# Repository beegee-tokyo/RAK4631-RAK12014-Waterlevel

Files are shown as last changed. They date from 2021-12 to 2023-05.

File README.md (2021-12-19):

----
----
# _RAK12014 Laser TOF sensor coming soon_
----
----

# WisBlock Watertank Level Sensor

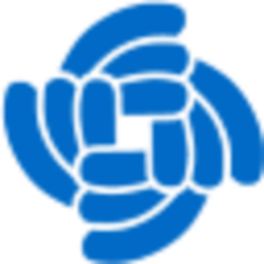
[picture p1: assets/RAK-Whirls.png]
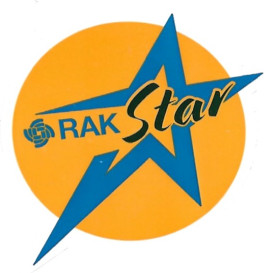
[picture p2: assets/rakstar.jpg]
RAKstar
|  |  | RAKstar | 
| :-: | :-: | :-: |

Watertank Overflow detection using the **RAKwireless WisBlock** modules. It implements as well a trick to wake up the device from sleep by knocking on the enclosure. 

## _REMARK_
The code is based on my low power event driven [WisBlock API](https://github.com/beegee-tokyo/WisBlock-API)

----

# Background
Here in the Philippines it is essential to have a water tank, because it is (unfortunately) still quite common that the water supply is cut off.    
After I got my tank installed, I experienced several time that the floating valve that controls the refill of the tank got stuck and the tank was overflowing for hours before I detected it.    
As there is no outlet close to the water tank, I needed a low power, solar recharged overflow sensor that can transmit the data over a longer distance.     
**RAKWireless WisBlock** has all components I needed to build my overflow sensor.    
- **RAK19003 & RAK4631** ==> The base board, battery supply, solar charger, MCU with LPWAN capability
- **RAK12014** ==> WisBlock Laser ToF sensor to measure the water level
- **RAK1904** ==> Acceleration sensor. This is not used for the overflow detection, it is used to wake up the system and activate the BLE. As the system is sleeping most of the time the BLE is of course switched off to save battery. I needed a solution to wake up the MCU and activate the BLE, so that I can access the device and setup its parameters. To wake up the system, you knock-knock on the enclosure. This vibrations are detected by the acceleration sensor, which generates an interrupt to wake up the system.
- **Solar Board** => A small 5V solar panel to recharge the battery during the day.

The enclosure is not IP65 but can protect the electronics from water intrusion unless the device is submerged into the water. It was designed using Fusion 360. The data files for the enclosure and the small solar panel can be found in the [./assets/3D](./assets/3D) folder.

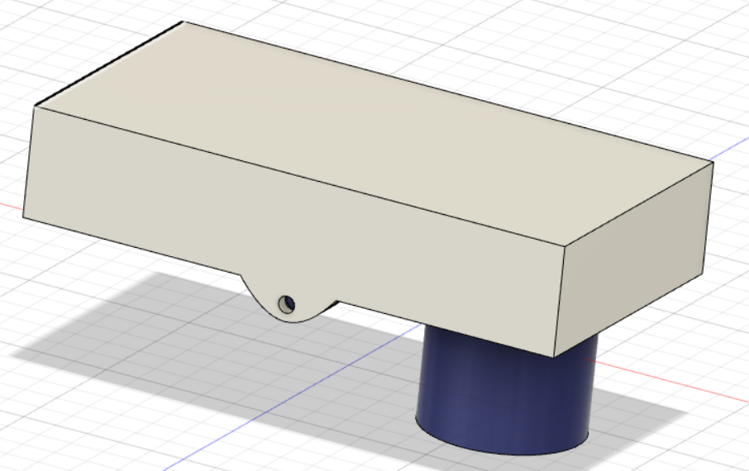
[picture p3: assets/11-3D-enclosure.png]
Enclosure
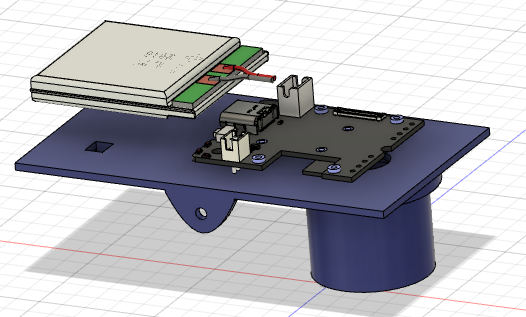
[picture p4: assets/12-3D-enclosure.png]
Enclosure
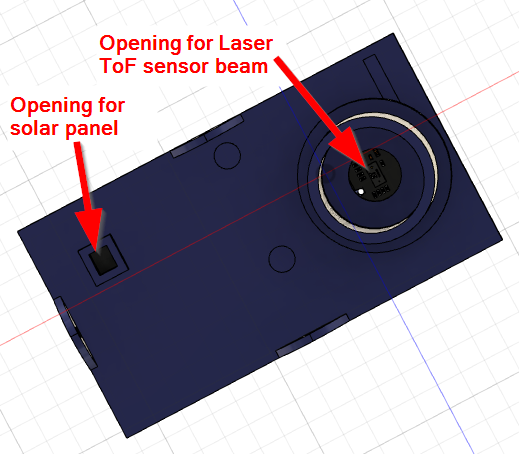
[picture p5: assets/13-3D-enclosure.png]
Enclosure
|  |  |  | 
| :-: | :-: | :-: |

# Dataflow
The sensor wakes up every 1 minute (configurable) and measures the distance between the Laser ToF sensor and the water surface. It packs the data into a data package in [Cayenne LPP format](https://community.mydevices.com/t/cayenne-lpp-2-0/7510) and includes:    
- Alarm status Overflow (digital output)
- Alarm status Low Level (digital output)
- Measured distance to water level (analog output). It is not the calculated water level, just the value read from the Laser ToF sensor. For my water tank the distance between the sensor and the bottom is around 1200mm. If the measured distance is larger than that, the value is discarded. The reason that such values are measured is because the water surface is not an ideal surface for measurement with the Laser ToF. Waves, sprinkling water while refilling can lead to false values.      
At a level of ~20, the water level is just below the sensor and the tank starts to overflow.    
- The battery level of the system (analog output).

The data format is
```c++
uint8_t data_flag0 = 0x01; // 1 Channel # 1
uint8_t data_flag1 = 0x02; // 2 Analog Input
uint8_t level_1 = 0;	   // 3 Water level
uint8_t level_2 = 0;	   // 4 Water level
uint8_t data_flag2 = 0x02; // 5 Channel # 2
uint8_t data_flag3 = 0x02; // 6 Analog Input
uint8_t batt_1 = 0;	   // 7 Battery level
uint8_t batt_2 = 0;	   // 8 Battery level
uint8_t data_flag4 = 0x03; // 9 Channel # 3
uint8_t data_flag5 = 0x66; // 10 Presence sensor (Alarm)
uint8_t alarm_of = 0;	   // 11 Alarm flag overflow
uint8_t data_flag6 = 0x04; // 12 Channel # 4
uint8_t data_flag7 = 0x66; // 13 Presence sensor (Alarm)
uint8_t alarm_ll = 0;	   // 14 Alarm flag low level
```

The data is sent as a LPWAN packet over a [RAK7258 gateway](https://docs.rakwireless.com/Product-Categories/WisGate/RAK7258/Overview) to a local Chirpstack LPWAN server.    
The Chirpstack LPWAN server has two integrations enabled:
- Datacake. Instructions can be found in [Chirpstack to Datacake tutorial](https://news.rakwireless.com/how-to-visualize-your-sensor-data-on-datacake-using-chirpstack-server/)
- Cayenne LPP MyDevices    

Once Chirpstack has received a data packet for the Overflow sensor, it forwards the data to the two integrations.    
I used Datacake because it is a very comfortable tool to visualize the data:      

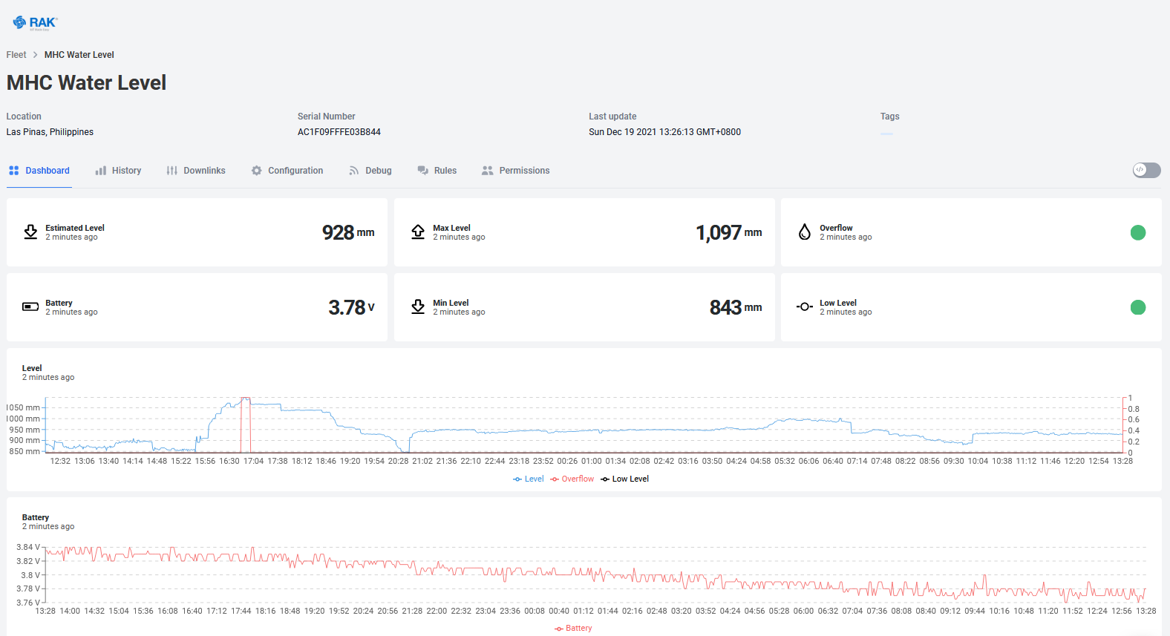
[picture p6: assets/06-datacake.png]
Datacake Dashboard
    

In Datacake you can setup _**rules**_ that can send out on email on events. I use it to send an email if the Alarm value is true:

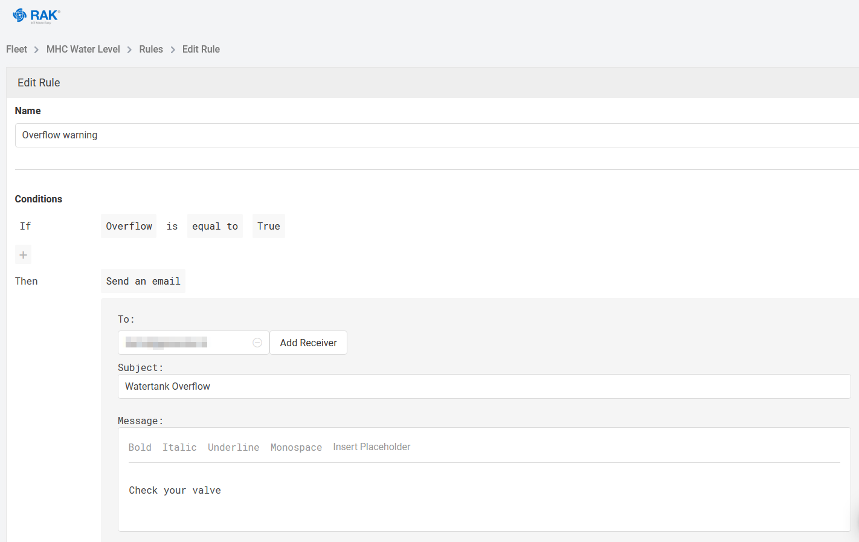
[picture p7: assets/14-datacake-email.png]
Datacake Email


And I added Cayenne LPP MyDevices, because it has more features to take actions on events by using _**triggers**_.

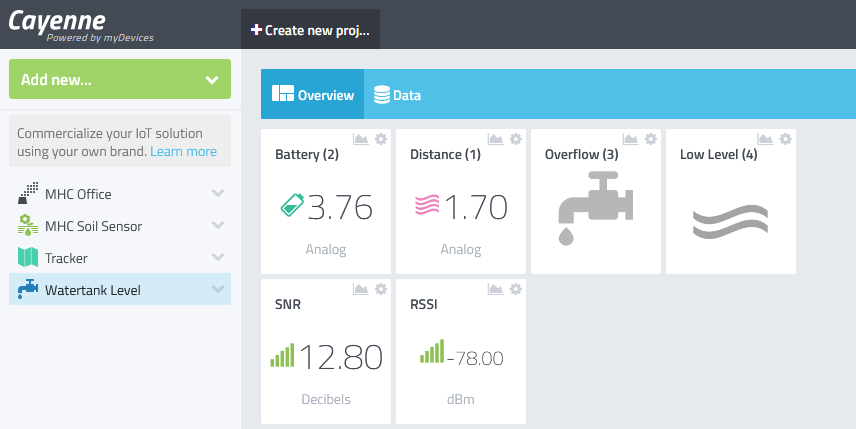
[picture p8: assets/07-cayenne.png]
Cayenne Dashboard
    

The data **`Alarm`** is connected to a Cayenne LPP MyDevices _**trigger**_ that sends an email and a text message if the overflow sensor sends an alarm:    

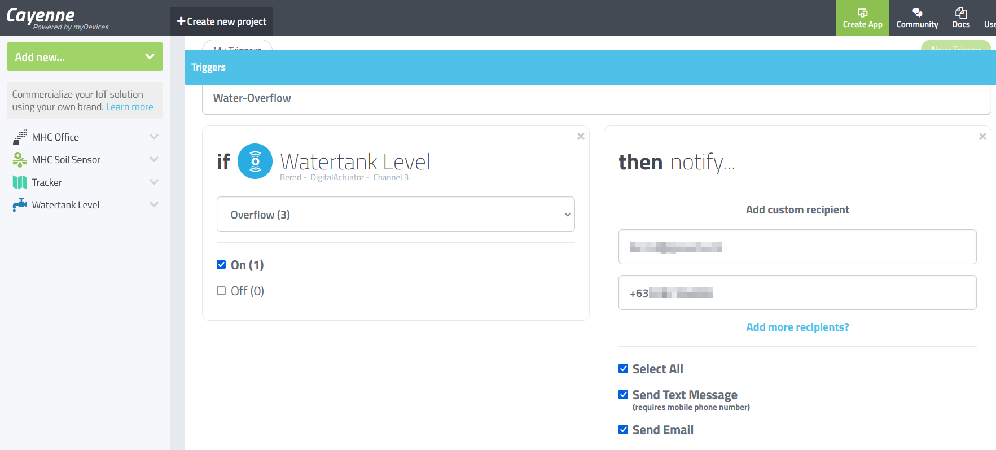
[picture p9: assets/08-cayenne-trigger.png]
Cayenne Alarm Trigger
    

The received alarm messages:

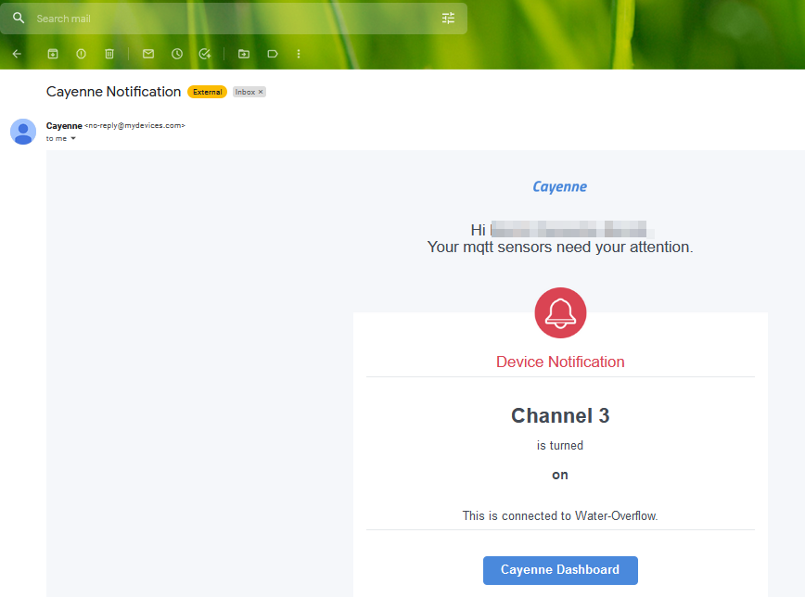
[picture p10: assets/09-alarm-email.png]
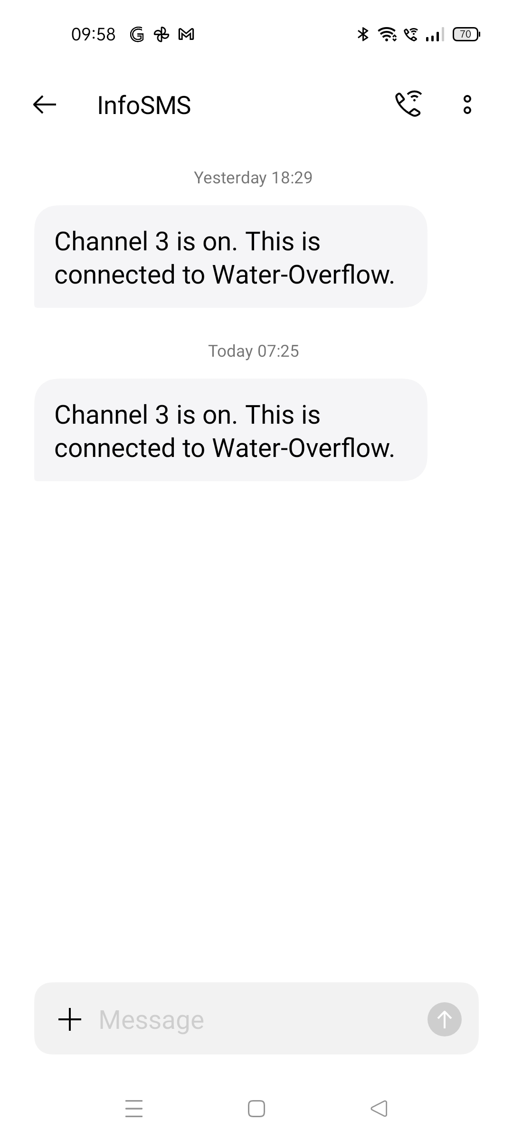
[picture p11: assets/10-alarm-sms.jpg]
|  |  | 
| :-: | :-: |

----

# Power supply and assembly of the sensor
The sensor uses a small 400mAh battery, which is sufficient for this application, as the sensor is only 10 seconds active every 1 minute.     
The battery is recharged during the day by a solar panel. The panel I used is 5V output panel, so that I can directly connect it to the WisBlock Base board.

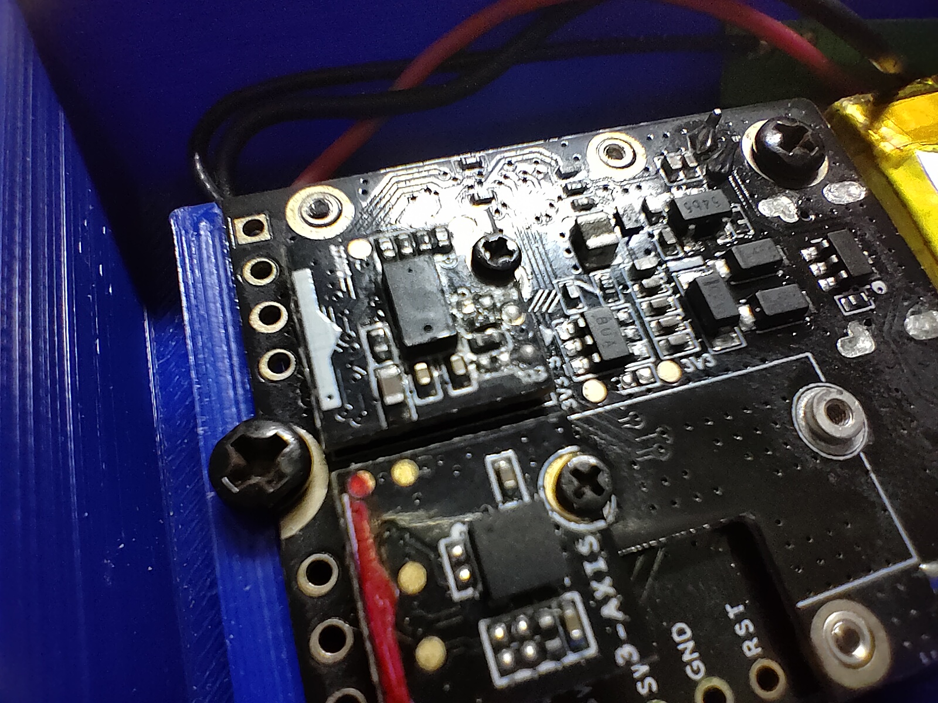
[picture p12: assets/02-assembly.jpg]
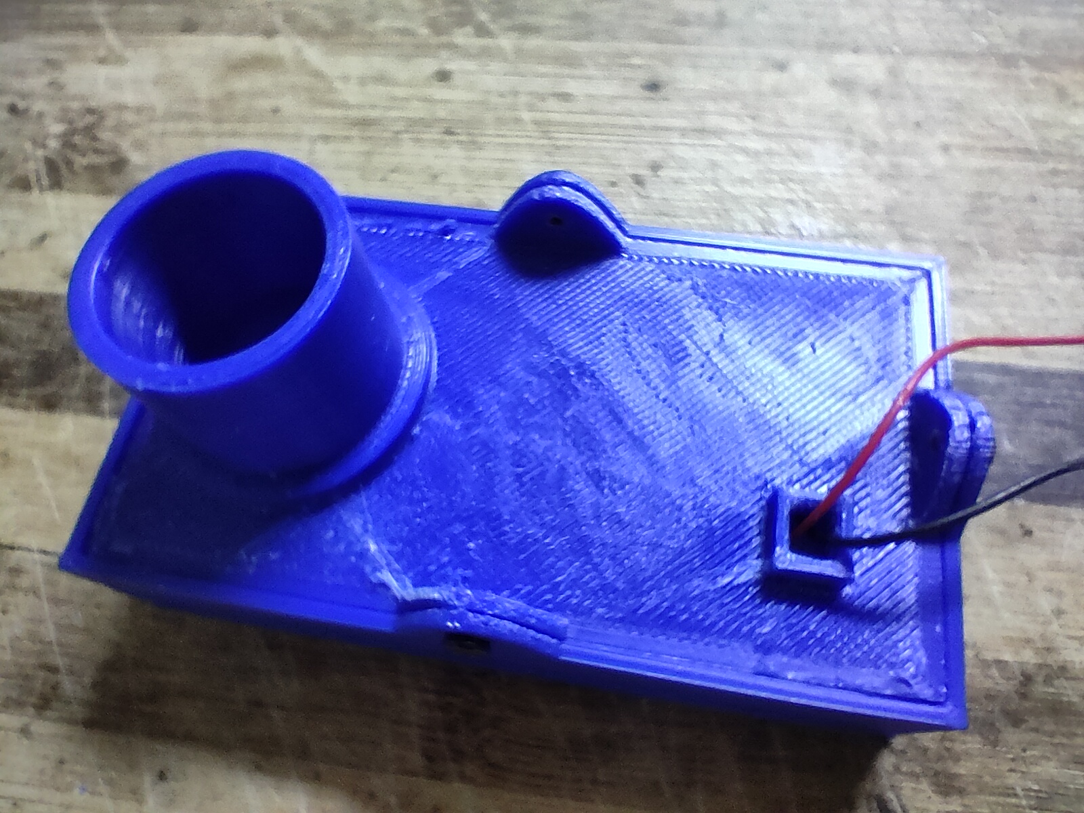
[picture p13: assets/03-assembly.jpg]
| Modules |  |  | 
| :-: | :-: | :-: |

----

# Installation  
The sensor is installed in an unused refill hole of the watertank. The 3D printed enclosure has a pipe that matches the diameter of the refill opening:

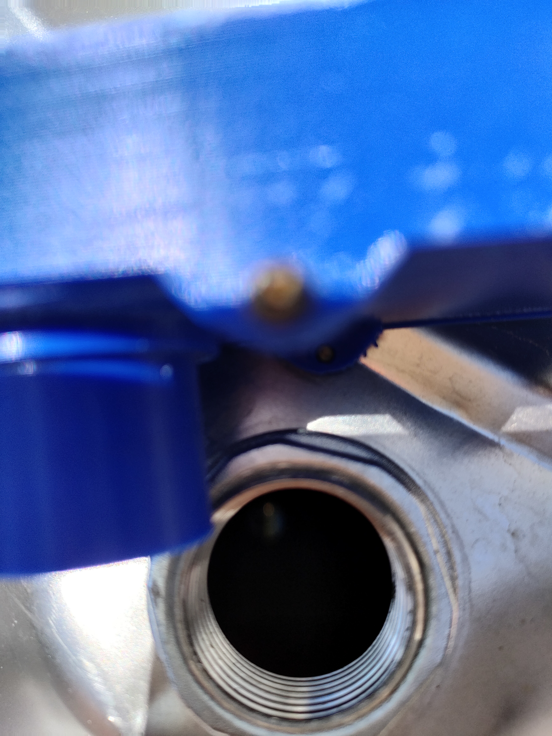
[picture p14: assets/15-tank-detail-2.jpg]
| Modules |  | 
| :-: | :-: |

The sensor is just loose in the refill opening and the solar panel is placed on top of the water tank:

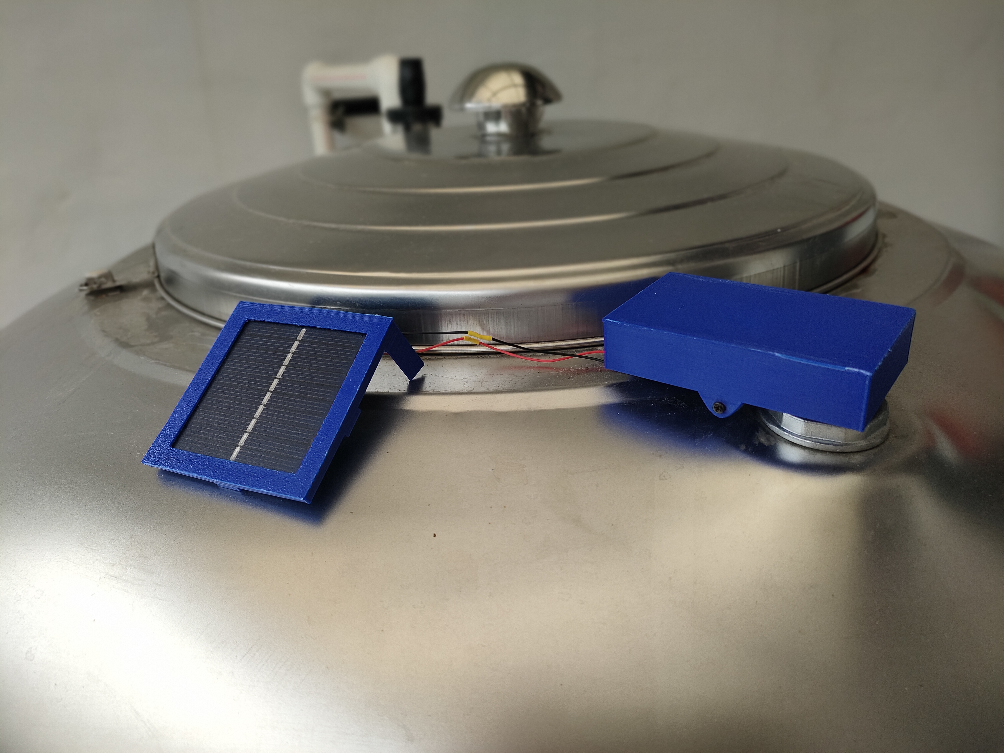
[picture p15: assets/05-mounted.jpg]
| Modules |  | 
| :-: | :-: |

To protect the inside of the enclosure against condensing water from the tank the opening at the Laser ToF sensor is sealed with a peace of plastic glued to the enclosure:    

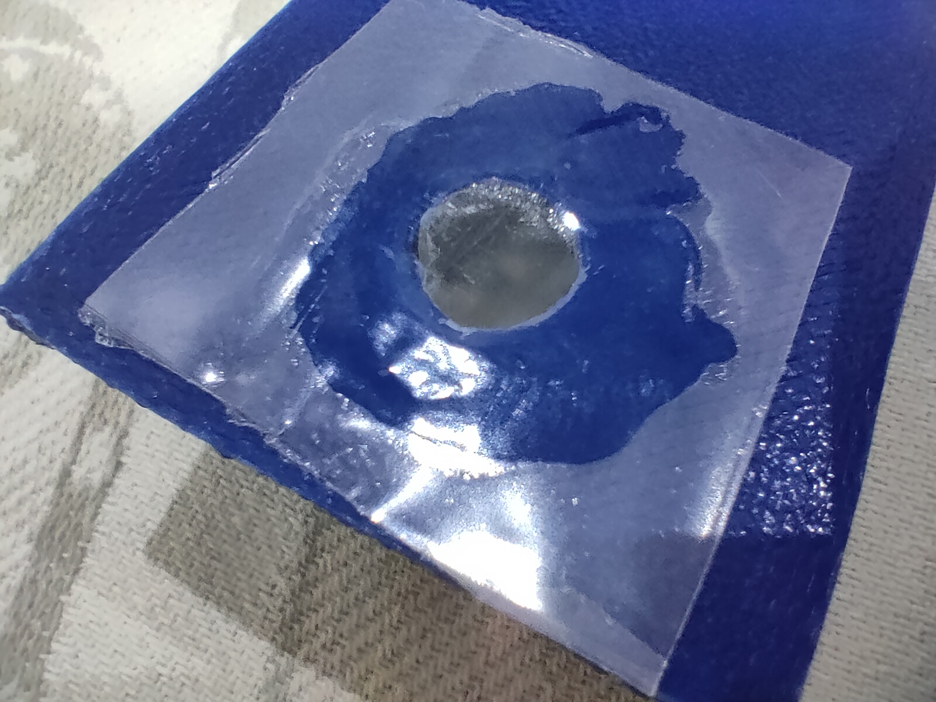
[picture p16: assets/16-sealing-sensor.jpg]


----

# How to wake up the sensor
To lower battery consumption, the device advertise its services (LPWAN setup and BLE UART) only for 30 seconds after power up. After that the BLE advertisement is shut off.    
But sometimes the BLE connection is required to change settings, update the firmware over BLE or debug over BLE UART.
To avoid opening the device or do a power cycle to restart the BLE advertising, I added the RAK1904 accelerometer and set it up so that it triggers an interrupt if it detects a movement in any direction. If the interrupt is triggered, the device wakes up and enables the BLE advertising for 15 seconds, so that the WisBlock Toolbox can connect to it.

To trigger the interrupt, a simple knock-knock on the enclosure is sufficient to be detected by the accelerometer.

----

# Hardware used
- [RAK4631](https://docs.rakwireless.com/Product-Categories/WisBlock/RAK4631/Overview/) WisBlock Core module
- [RAK19003](https://docs.rakwireless.com/Product-Categories/WisBlock/RAK19003/Overview/) WisBlock Base board
- [RAK12014](https://docs.rakwireless.com/Product-Categories/WisBlock/RAK12017/Overview/) WisBlock Laser ToF sensor
- [RAK1904](https://docs.rakwireless.com/Product-Categories/WisBlock/RAK1904/Overview) WisBlock Acceleration sensor
- [Solar Board](https://store.rakwireless.com/products/solar-board-1?_pos=1&_sid=cbf51f193&_ss=r) RAKWireless solar panel    

## Power consumption
The application does switch off the Laser ToF module and the MCU and LoRa transceiver go into sleep mode between measurement cycles to save power. I could measure a sleep current of 20-40uA of the whole system. 

----

# Software used
- [PlatformIO](https://platformio.org/install)
- [Adafruit nRF52 BSP](https://docs.platformio.org/en/latest/boards/nordicnrf52/adafruit_feather_nrf52832.html)
- [Patch to use RAK4631 with PlatformIO](https://github.com/RAKWireless/WisBlock/blob/master/PlatformIO/RAK4630/README.md)
- [SX126x-Arduino LoRaWAN library](https://github.com/beegee-tokyo/SX126x-Arduino)
- [WisBlock-API](https://platformio.org/lib/show/12807/WisBlock-API)
- [SparkFun LIS3DH Arduino Library](https://platformio.org/lib/show/1401/SparkFun%20LIS3DH%20Arduino%20Library)
- [Pololu VL53L0X Library](https://platformio.org/lib/show//854/VL53L0X)

## _REMARK_
The libraries are all listed in the **`platformio.ini`** and are automatically installed when the project is compiled.

----

# Setting up LoRaWAN credentials
The LoRaWAN settings can be defined in three different ways. 
- Over BLE with [WisBlock Toolbox](https://play.google.com/store/apps/details?id=tk.giesecke.wisblock_toolbox)
- Over USB with [AT Commands](./AT-Commands.md)
- Hardcoded in the sources (_**ABSOLUTELY NOT RECOMMENDED**_)

## 1) Setup over BLE
Using the [WisBlock Toolbox](https://play.google.com/store/apps/details?id=tk.giesecke.wisblock_toolbox) you can connect to the WisBlock over BLE and setup all LoRaWAN parameters like
- Region
- OTAA/ABP
- Confirmed/Unconfirmed message
- ...

More details can be found in the [WisBlock Toolbox](https://github.com/beegee-tokyo/WisBlock-Toolbox#readme)

The device is advertising over BLE only the first 30 seconds after power up and then again for 15 seconds after wakeup for measurements. The device is advertising as **`RAK-GNSS-xx`** where xx is the BLE MAC address of the device.

## 2) Setup over USB port
Using the AT command interface the WisBlock can be setup over the USB port.

A detailed manual for the AT commands are in [AT-Commands.md](https://github.com/beegee-tokyo/WisBlock-API/blob/main/AT-Commands.md) (_**external link**_)

Here is an example for the typical AT commands required to get the device ready (EUI's and Keys are examples):
```log
// Setup AppEUI
AT+APPEUI=70b3d57ed00201e1
// Setup DevEUI
AT+DEVEUI=ac1f09fffe03efdc
// Setup AppKey
AT+APPKEY=2b84e0b09b68e5cb42176fe753dcee79
// Set automatic send frequency in seconds
AT+SENDFREQ=60
// Set data rate
AT+DR=3
// Set LoRaWAN region (here US915)
AT+BAND=8
// Reset node to save the new parameters
ATZ
// After reboot, start join request
AT+JOIN=1,0,8,10
```

## _REMARK_
The AT command format used here is _**NOT**_ compatible with the RAK5205/RAK7205 AT commands.

## 3) Hardcoded LoRaWAN settings
`void api_set_credentials(void);`
This informs the API that hard coded LoRaWAN credentials will be used. If credentials are sent over USB or from My nRF Toolbox, the received credentials will be ignored. _**It is strongly suggest NOT TO USE hard coded credentials to avoid duplicate node definitions**_    
If hard coded LoRaWAN credentials are used, they must be set before this function is called. Example:    
```c++
g_lorawan_settings.auto_join = false;							// Flag if node joins automatically after reboot
g_lorawan_settings.otaa_enabled = true;							// Flag for OTAA or ABP
memcpy(g_lorawan_settings.node_device_eui, node_device_eui, 8); // OTAA Device EUI MSB
memcpy(g_lorawan_settings.node_app_eui, node_app_eui, 8);		// OTAA Application EUI MSB
memcpy(g_lorawan_settings.node_app_key, node_app_key, 16);		// OTAA Application Key MSB
memcpy(g_lorawan_settings.node_nws_key, node_nws_key, 16);		// ABP Network Session Key MSB
memcpy(g_lorawan_settings.node_apps_key, node_apps_key, 16);	// ABP Application Session key MSB
g_lorawan_settings.node_dev_addr = 0x26021FB4;					// ABP Device Address MSB
g_lorawan_settings.send_repeat_time = 120000;					// Send repeat time in milliseconds: 2 * 60 * 1000 => 2 minutes
g_lorawan_settings.adr_enabled = false;							// Flag for ADR on or off
g_lorawan_settings.public_network = true;						// Flag for public or private network
g_lorawan_settings.duty_cycle_enabled = false;					// Flag to enable duty cycle (validity depends on Region)
g_lorawan_settings.join_trials = 5;								// Number of join retries
g_lorawan_settings.tx_power = 0;								// TX power 0 .. 15 (validity depends on Region)
g_lorawan_settings.data_rate = 3;								// Data rate 0 .. 15 (validity depends on Region)
g_lorawan_settings.lora_class = 0;								// LoRaWAN class 0: A, 2: C, 1: B is not supported
g_lorawan_settings.subband_channels = 1;						// Subband channel selection 1 .. 9
g_lorawan_settings.app_port = 2;								// Data port to send data
g_lorawan_settings.confirmed_msg_enabled = LMH_UNCONFIRMED_MSG; // Flag to enable confirmed messages
g_lorawan_settings.resetRequest = true;							// Command from BLE to reset device
g_lorawan_settings.lora_region = LORAMAC_REGION_AS923_3;		// LoRa region
// Inform API about hard coded LoRaWAN settings
api_set_credentials();
```

_**REMARK!**_    
Hard coded credentials must be set in `void setup_app(void)`!

----

# Packet data format
The packet data is in Cayenne LPP format. Every time the sensor data are collected, they are stored in a structure that is build in a format that most LPWAN servers and Integrations can easily parse. See [Dataflow](#dataflow) for details of the packet data format.

----

# Compiled output
The compiled files are located in the [./Generated](./Generated) folder. Each successful compiled version is named as      
**`WisBlock_WL_Vx.y.z_YYYY.MM.dd.hh.mm.ss`**    
x.y.z is the version number. The version number is setup in the [./platformio.ini](./platformio.ini) file.    
YYYY.MM.dd.hh.mm.ss is the timestamp of the compilation.

The generated **`.zip`** file can be used as well to update the device over BLE using either [My nRF52 Toolbox repo](https://github.com/beegee-tokyo/My-nRF52-Toolbox/blob/master/README.md) or [Nordic nRF Toolbox](https://play.google.com/store/apps/details?id=no.nordicsemi.android.nrftoolbox) or [nRF Connect](https://play.google.com/store/apps/details?id=no.nordicsemi.android.mcp)

----

# Debug options 
Debug output can be controlled by defines in the **`platformio.ini`**    
_**LIB_DEBUG**_ controls debug output of the SX126x-Arduino LoRaWAN library
 - 0 -> No debug outpuy
 - 1 -> Library debug output (not recommended, can have influence on timing)    

_**MY_DEBUG**_ controls debug output of the application itself
 - 0 -> No debug outpuy
 - 1 -> Application debug output

_**CFG_DEBUG**_ controls the debug output of the nRF52 BSP. It is recommended to keep it off

## Example for no debug output and maximum power savings:

```ini
[env:wiscore_rak4631]
platform = nordicnrf52
board = wiscore_rak4631
framework = arduino
build_flags = 
	; -DCFG_DEBUG=2
	-DSW_VERSION_1=1 ; major version increase on API change / not backwards compatible
	-DSW_VERSION_2=0 ; minor version increase on API change / backward compatible
	-DSW_VERSION_3=0 ; patch version increase on bugfix, no affect on API
	-DLIB_DEBUG=0    ; 0 Disable LoRaWAN debug output
	-DMY_DEBUG=0     ; 0 Disable application debug output
	-DNO_BLE_LED=1   ; 1 Disable blue LED as BLE notificator
lib_deps = 
	beegee-tokyo/SX126x-Arduino
	sparkfun/SparkFun LIS3DH Arduino Library
	beegee-tokyo/WisBlock-API
extra_scripts = pre:rename.py
```

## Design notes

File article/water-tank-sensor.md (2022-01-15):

---
sidebar: false
rak_img: ./assets/05-mounted.jpg
rak_desc: An use case for the RAK12014 Laser ToF sensor
tags:
   - Building Control System
   - Water Tank Sensor
   - Time of Flight Sensor
   - Water shortage Sensor
   - Water overflow Sensor
   - Battery powered System
   - Solar panel backup
   - WisBlock  
   - RAK19003
   - RAK4631
   - RAK1904
   - RAK12014
header:
  title: WisBlock Solution - Water Tank Level and Overflow Sensor
  caption: by <b>Bernd Giesecke</b> 
  img: ./assets/rakstar.jpg
posted: 02/16/2022 10:30 AM
author:
  name: Bernd Giesecke
  about: Electronics Engineer, 23 years experience in industrial and automotive HW and SW R&D. Supporting Arduino open source community since 2014.
  img: /assets/images/knowledge-hub/authors/bernd-giesecke.png
---

# WisBlock Solution - Water Tank Level and Overflow Sensor

## Featuring WisBlock RAK12014 Laser ToF sensor

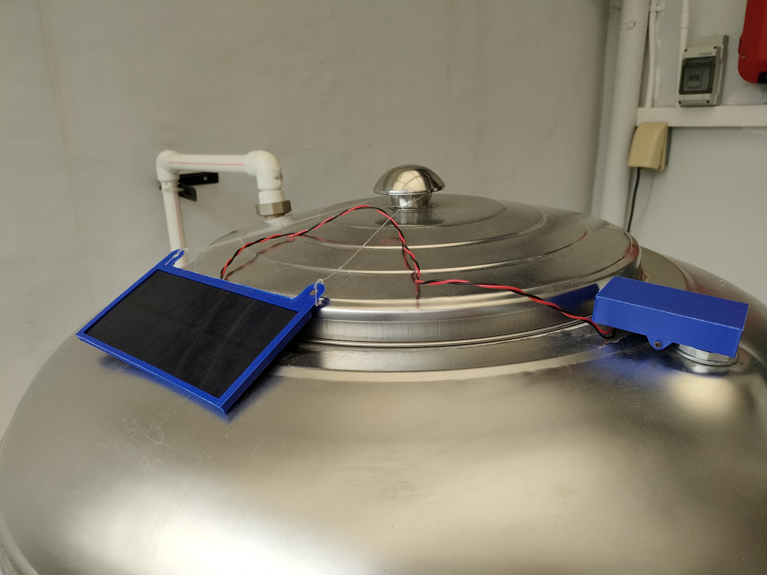
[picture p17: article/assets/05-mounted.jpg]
Deployed


In many areas having a water tank is crucial, may it be in rural areas or in third world countries where a continuous  water supply is not guaranteed.       
Water tanks are quite simple constructions, you have the tank itself, the pipe going to your house and the refill pipe with a very basic floating ball valve.  
  
There are two critical situations that should trigger a notification or alarm:
- Low level of the water in the tank because of discontinued water supply    
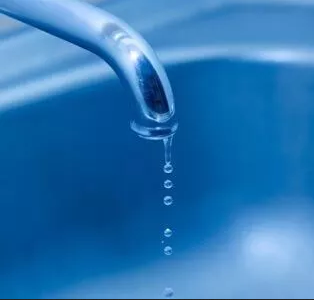
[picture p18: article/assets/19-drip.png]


- Water overflow because of malfunction of the floating ball valve    
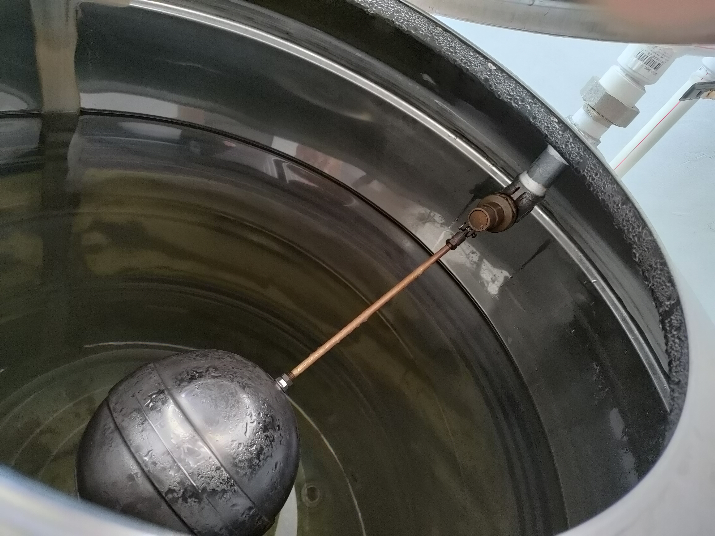
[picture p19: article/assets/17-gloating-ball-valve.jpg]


There are multiple options to detect these situations. Most of them require to submerge a sensor element in the water inside the tank. But such solutions can contaminate  the water in the tank, so another method to measure the water level is required.    

Two options for a contactless level measurement are using ultrasonic based sensors or ToF (time of flight) based sensors. As the openings in the tanks are quite small, a small sensor like the laser based ToF sensor is a good solution.

Other points to considerate are 
1) the power supply for the sensor
2) data transmission
3) status control and firmware update over the air without opening the sensor enclosure

For power supply a battery powered system is a good solution, as water tanks can be mounted on a high level, out of the reach of power outlets. To keep the sensor alive a small solar panel can be used to recharge the battery during day time.    

For data transmission, LoRaWAN is a perfect data transmission solution if the water tank is out of the range of WiFi or cellular signals.

And for the last part BLE is a good solution. It offers connection to the sensor without the need to connect to it with a cable. However, it will drain the battery, even if not in use.   
To get around the battery drain, an unusual idea came up. The BLE is switched off all the time. To enable BLE advertising, a 3-axis acceleration sensor inside the device is used as a virtual button. Knocking on the device enclosure sends vibration to the 3-axis sensor. These vibration trigger a motion interrupt from the acceleration sensor which then switches on the BLE advertising. This enables a BLE capable device (phone, tablet, laptop) to connect to the sensor and check or change the configuration or start an OTA DFU (over the air device firmware update).

Putting all above requirements together, the RAKWireless WisBlock modules are a perfect match to build a low power sensor system with a wide range communication capability. The WisBlock modules used in this proof-of-concept project are    

| | |
| --- | :-: |
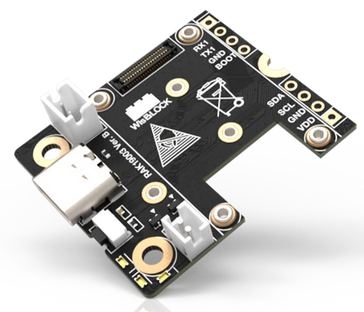
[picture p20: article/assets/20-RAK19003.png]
RAK19003
| [**RAK19003 WisBlock Mini Base Board**](https://store.rakwireless.com/products/wisblock-base-board-rak19003) |  |
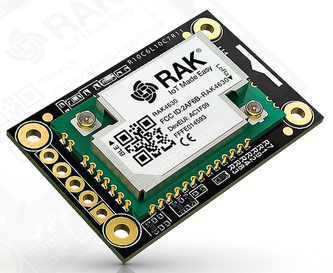
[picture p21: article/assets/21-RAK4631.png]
RAK4631
| [**RAK4631 WisBlock Core module with BLE and LoRa**](https://store.rakwireless.com/products/rak4631-lpwan-node) |   |
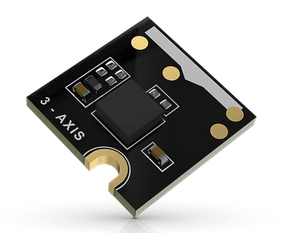
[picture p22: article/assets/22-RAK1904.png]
RAK1904
| [**RAK1904 WisBlock 3-axis acceleration sensor**](https://store.rakwireless.com/products/rak1904-lis3dh-3-axis-acceleration-sensor) |   |
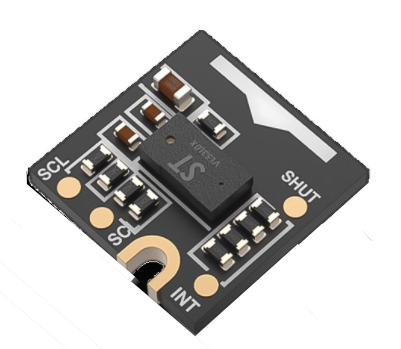
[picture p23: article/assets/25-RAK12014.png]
RAK12014
| [**RAK12014 WisBlock Laser ToF sensor**](https://store.rakwireless.com/products/rak12014-wisblock-tof-sensor) |   |
<center>Assembly</center>

Using the WisBlock Mini Base Board makes it possible to design a small enclosure with only 83x47x19mm and still have space for a 400mAh battery inside. The small battery and the solar panel backup together with a deep-sleep current of only 30uA secures the uninterrupted function of the device even over rainy days.

The RAK4631 WisBlock Core module has the LoRa and BLE communication integrated and offers low consumption deep sleep mode.

The RAK1904 WisBlock Acceleration Sensor is used as the virtual switch to wake up the device for BLE communication.

And the RAK12014 Laser ToF sensor is the solution to have a contactless measurement of the water level inside the tank. It's range of 1.5m is sufficient for medium size tanks.

## The solution and some obstacles on the way

The hardware setup and mechanic design looked simple at first. However, some things came up during the design.  
  
The first one was how to deploy the sensor itself. The simplest solution was to make the sensor enclosure design to fit directly into a spare opening of the water tank. The enclosure shape includes a tube that fit's directly into opening of the water tank.

| | |
| --- | :-: |
|  Mounting 1 |  Mounting 2 |

Here the first approach (shown in the images above) was to make the tube on the enclosure long to avoid it to wiggle. But that collided with the sensor specifications. Both the laser transmitting diode and the receiving diode have a characteristic for the distribution and the receiving beams. The first design with the long tube didn't match with these beams and the tube itself created reflections of the laser beam that led to wrong measurements.  
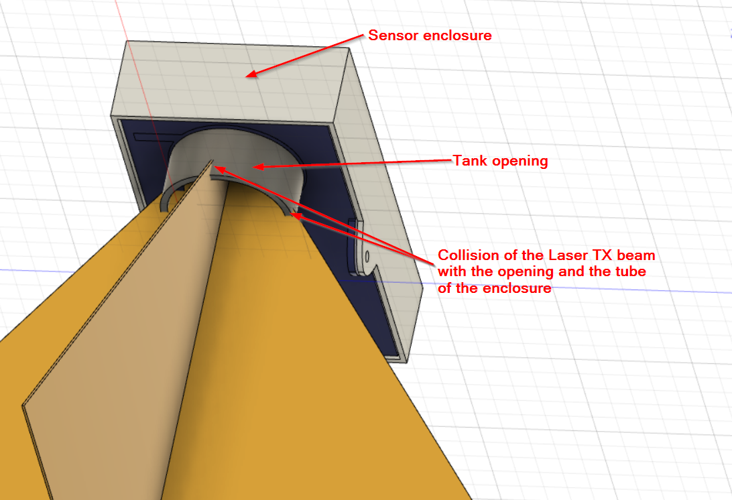
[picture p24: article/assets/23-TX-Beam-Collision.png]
Laser collision


Changing the depth of the tube and placing the sensor lower in the enclosure fixed the problem.
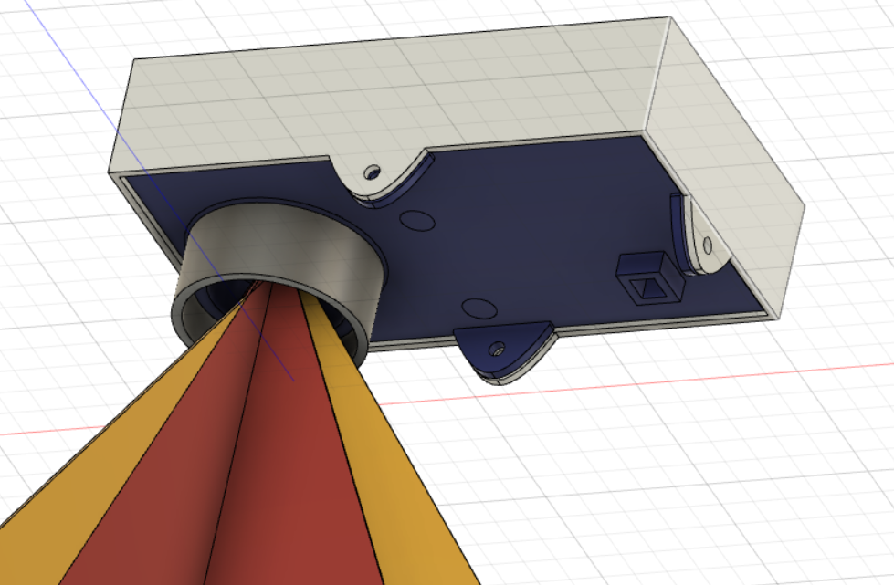
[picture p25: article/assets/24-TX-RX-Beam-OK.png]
Laser no collision


## Data transfer and visualization

The firmware of the sensor is measuring the water level every 1 minute and stays otherwise in deep sleep as long as possible. After measuring, the data is decoded in Cayenne LPP format, which makes it very easy to visualize it on different platforms like [Cayenne myDevices](https://mydevices.com/) or [Datacake](https://datacake.co/).

The data includes not only the water level itself, but as well the battery voltage and alarm flags for overflow and low water level detection. A detailed description of the data packet format can be found in the [firmware repo](https://github.com/beegee-tokyo/RAK4631-RAK12014-Waterlevel#dataflow).

The alarm flags for overflow and low level are calculated in the sensor itself. To do this thresholds are set in source code as well as estimated maximum depth of the water tank. The measured water level (depth of the tank - measured distance) is then compared to the thresholds and the alarm flags are set if the thresholds are higher.

The first step in the data transfer is the transmission of the data packet to a LoRaWAN gateway. The gateway will forward the packet to a LoRaWAN server like [TTN](https://www.thethingsnetwork.org) or [Chirpstack](https://www.chirpstack.io).    

Then applications in the LoRaWAN server application can be used to forward the data to visualization platforms. In the RAK News blog [How to Visualize Your Sensor Data on Datacake Using the Chirpstack Server](https://news.rakwireless.com/how-to-visualize-your-sensor-data-on-datacake-using-chirpstack-server/) is a tutorial how to implement the visualization with Chirpstack and Datacake.  
  
Here is an example of the visualization in Datacake:    
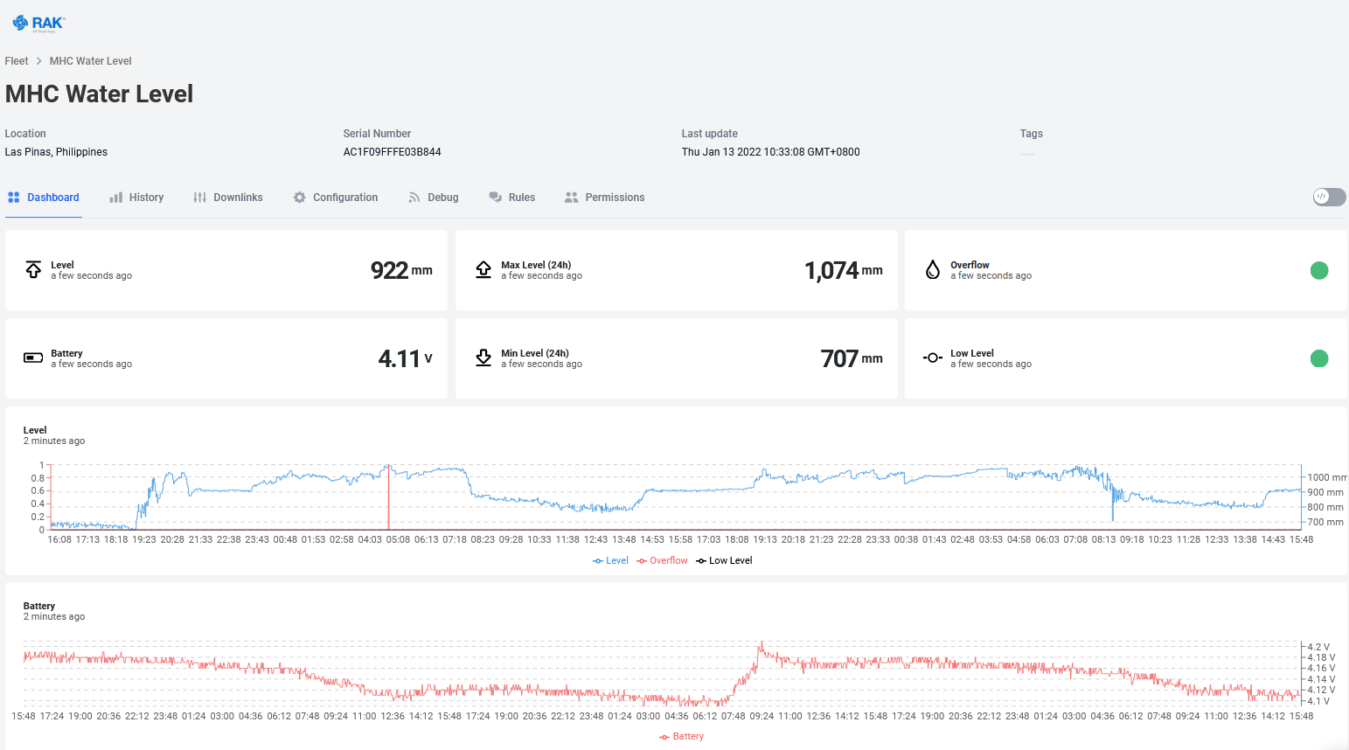
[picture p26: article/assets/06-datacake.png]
Datacake


You can see as well the live data in this [Datacake Dashboard](https://app.datacake.de/dashboard/d/6a618495-9c10-4993-941e-96807b5db34f)

And here is the visualization in Cayenne myDevices:  
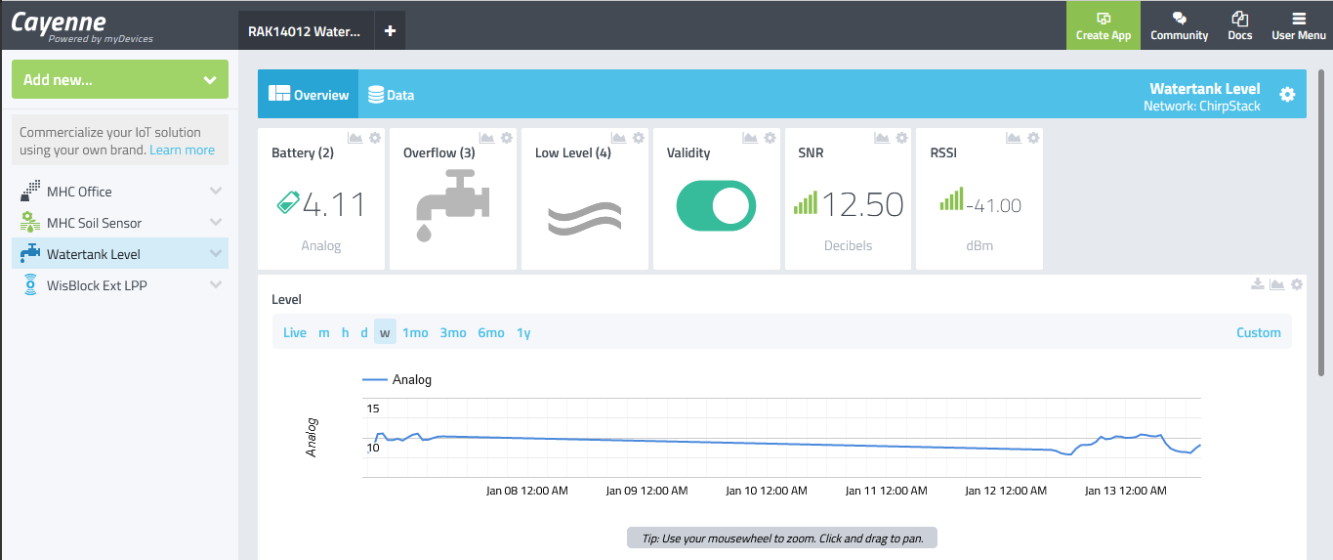
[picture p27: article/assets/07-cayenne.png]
Cayenne myDevices


Both Datacake and Cayenne myDevices offer as well the option to send out an alarm as email or text message if an overflow alert or low level alert was issued.    
The setup is quite simple and the received alarms arrive in the email box or message box of the phone:

| Email alert | Email alert |
| -- | :-: |
| Text message | SMS alert |

## More details
A more technical description of the project together with the source codes and the enclosure designs can be found in the [Github RAK4631-RAK12014-Waterlevel repo](https://github.com/beegee-tokyo/RAK4631-RAK12014-Waterlevel)

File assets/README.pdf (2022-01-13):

# RAK12017 IR TOF sensor coming soon

# WisBlock Watertank Overflow Detection

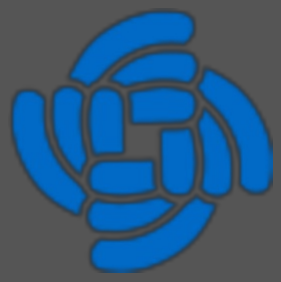
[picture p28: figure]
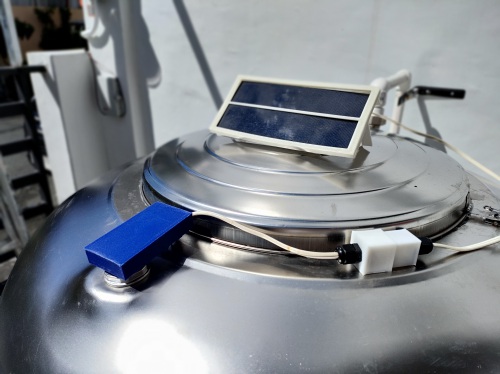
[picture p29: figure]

Watertank Overflow detection using the RAKwireless WisBlock modules. It implements as well a trick to wake up the device from sleep by knocking on the enclosure.

## REMARK

The code is based on my low power event driven WisBlock API (https://github.com/beegee-tokyo/WisBlock-API)

# Background

Here in the Philippines it is essential to have a water tank, because it is (unfortunately) still quite common that the water supply is cut off.
After I got my tank installed, I experienced several time that the floating valve that controls the refill of the tank got stuck and the tank was overflowing for hours before I detected it.
As there is no outlet close to the water tank, I needed a low power, solar recharged overflow sensor that can transmit the data over a longer distance.
RAKWireless WisBlock has all components I needed to build my overflow sensor.

RAK5005-O & RAK4631 ==> The base board, battery supply, solar charger, MCU with LPWAN capability

RAK12017 ==> WisBlock IR ToF sensor to measure the water level

RAK1904 ==> Acceleration sensor. This is not used for the overflow detection, it is used to wake up the system and activate the BLE. As the system is sleeping most of the time and the BLE is of course switched off to save battery, I needed a solution to wake up the MCU and activate the BLE, so that I can access the device and setup its parameters. To wake up the system, you knock-knock on the enclosure. This vibrations are detected by the acceleration sensor, which generates an interrupt to wake up the system.

The enclosure is not IP65 but can protect the electronics from water intrusion unless the device is submerged into the water. It was designed using Fusion 360. The data files for the enclosure can be found in the ./assets/3D folder.

### RAK4631-RAK12017-Waterlevel

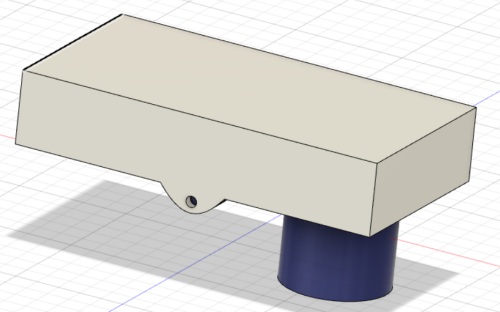
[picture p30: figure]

# Dataflow

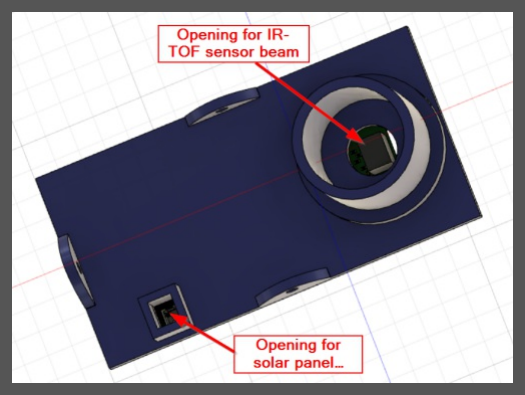
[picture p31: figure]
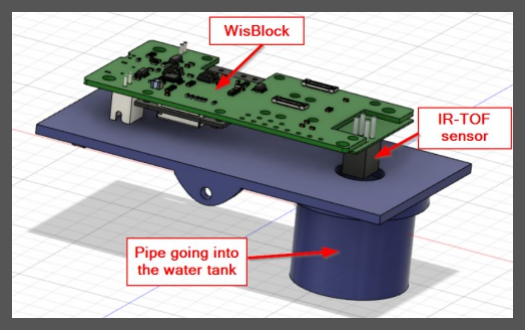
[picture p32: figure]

The sensor wakes up every 1 minute (configurable) and measures the distance between the IR ToF sensor and the water surface. It packs the data into a data package in Cayenne LPP format (https://community.mydevices.com/t/cayenne-lpp-2-0/7510) and includes:

Alarm status (digital output)

Measured distance to water level (analog output). It is not the calculated water level, just the value read from the IR ToF sensor. It is 4095 if the water level is below the range of the sensor (around 3cm) and gets lower if the water level raises. At a level of ~2300, the water level is just below the sensor and the tank starts to overflow.

The battery level of the system (analog output).

The data format is

uint8_t data_flag0 = 0x01; // 1 Channel # 1 uint8_t data_flag1 = 0x02; // 2 Analog Input uint8_t level_1 = 0; // 3 Water level uint8_t level_2 = 0; // 4 Water level uint8_t data_flag2 = 0x02; // 5 Channel # 2 uint8_t data_flag3 = 0x02; // 6 Analog Input uint8_t batt_1 = 0; // 7 Battery level uint8_t batt_2 = 0; // 8 Battery level uint8_t data_flag4 = 0x03; // 9 Channel # 3 uint8_t data_flag5 = 0x66; // 10 Presence sensor
uint8_t alarm = 0; // 11 Alarm flag

The data is sent as a LPWAN packet over a RAK7258 gateway (https://docs.rakwireless.com/Product-Categories/WisGate/RAK7258/Overview) to a local Chirpstack LPWAN server. The Chirpstack LPWAN server has two integrations enabled:

Datacake. Instructions can be found in Chirpstack to Datacake tutorial (https://news.rakwireless.com/how-to-visualize-your-sensor-data-on-datacake-using-chirpstack-server/)

Cayenne LPP MyDevices

Once Chirpstack has received a data packet for the Overflow sensor, it forwards the data to the two integrations.
I used Datacake because it is a very comfortable tool to visualize the data:

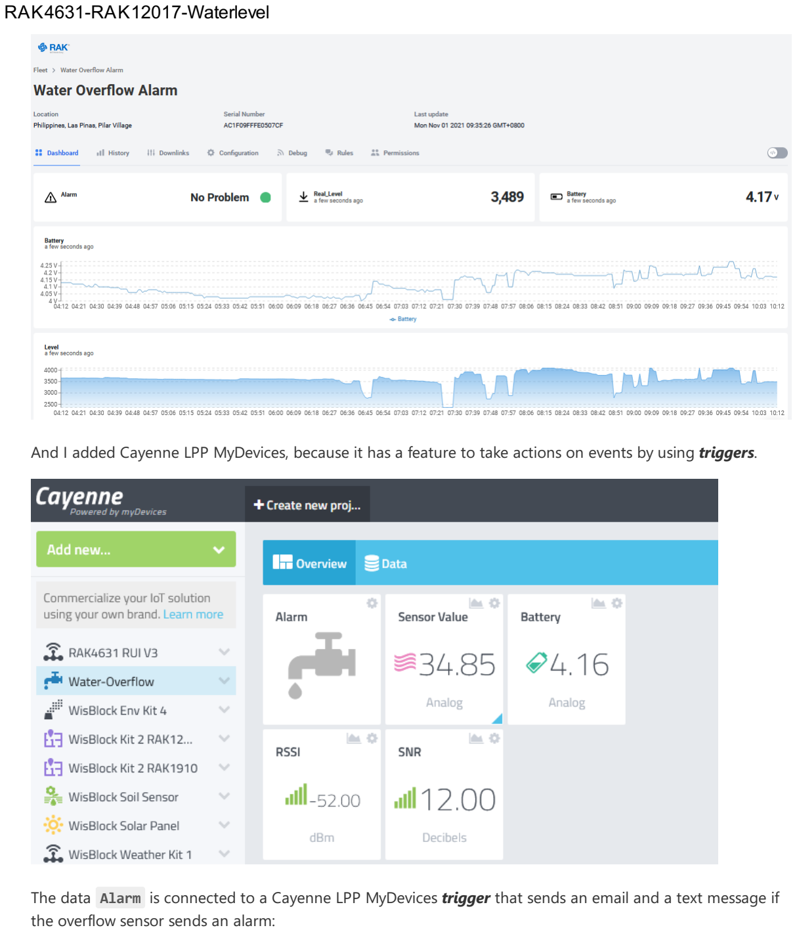
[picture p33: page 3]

And I added Cayenne LPP MyDevices, because it has a feature to take actions on events by using triggers.

The data Alarm is connected to a Cayenne LPP MyDevices trigger that sends an email and a text message if the overflow sensor sends an alarm:

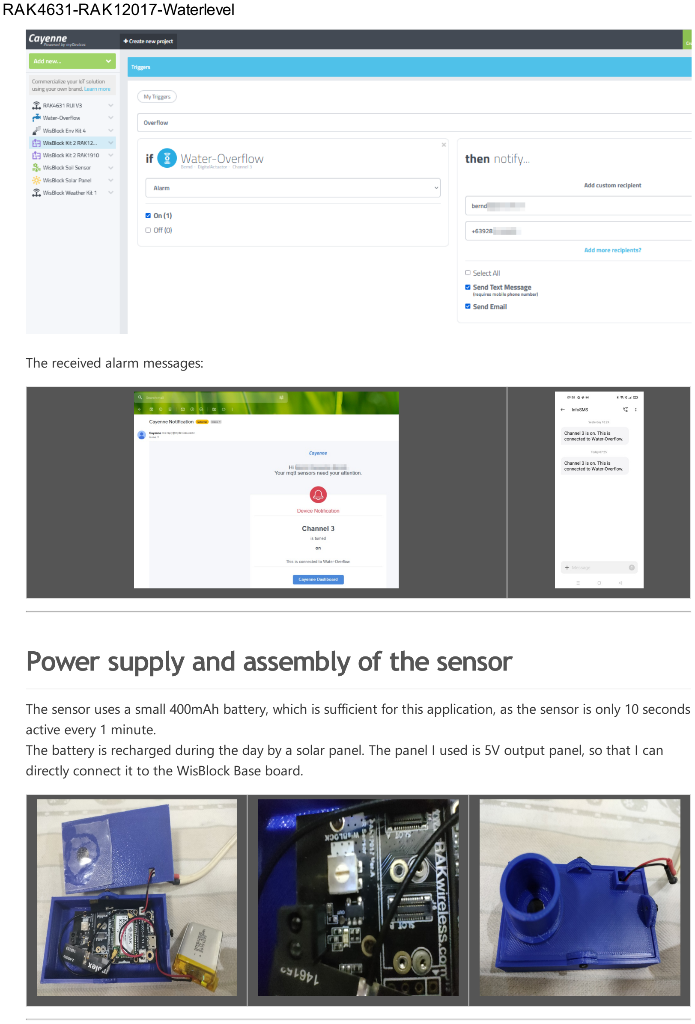
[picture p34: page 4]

The received alarm messages:

# Power supply and assembly of the sensor

The sensor uses a small 400mAh battery, which is sufficient for this application, as the sensor is only 10 seconds active every 1 minute.
The battery is recharged during the day by a solar panel. The panel I used is 5V output panel, so that I can directly connect it to the WisBlock Base board.

# Installation

The sensor is installed in an unused refill hole of the watertank. The 3D printed enclosure has a pipe that matches the diameter of the refill opening:

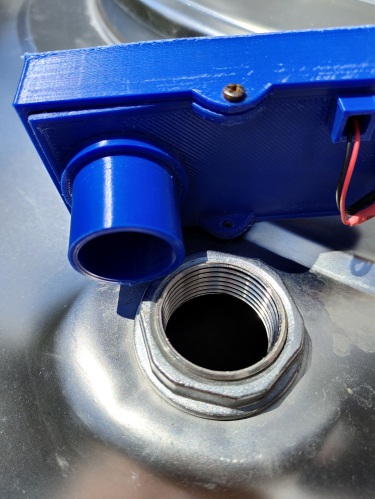
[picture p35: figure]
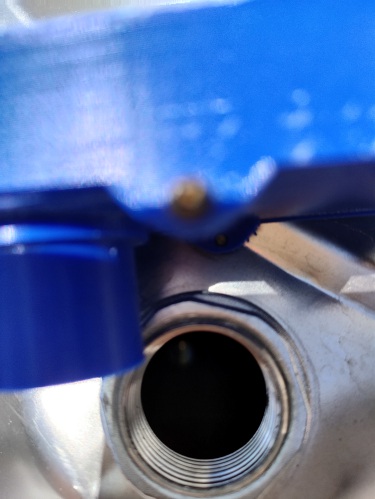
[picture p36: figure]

The sensor is just loose in the refill opening and the solar panel is placed on top of the water tank:

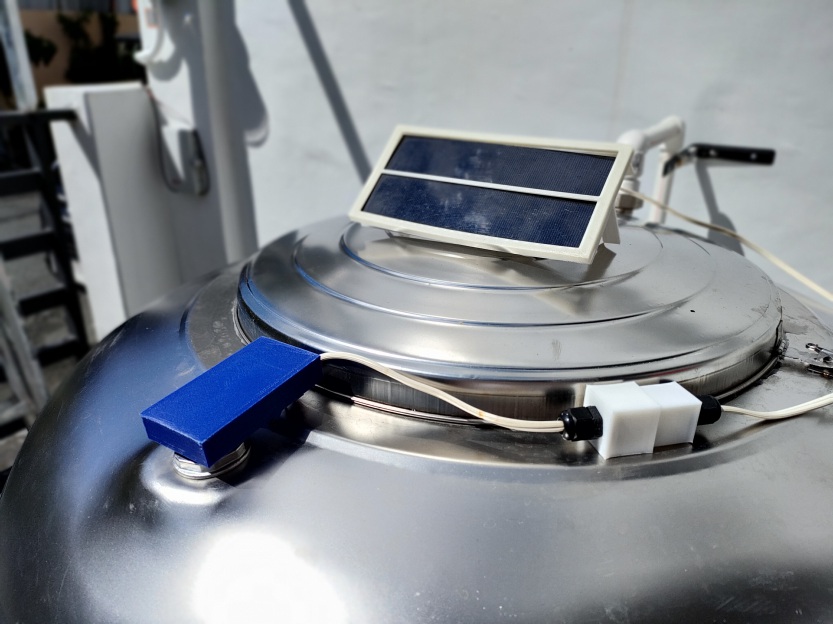
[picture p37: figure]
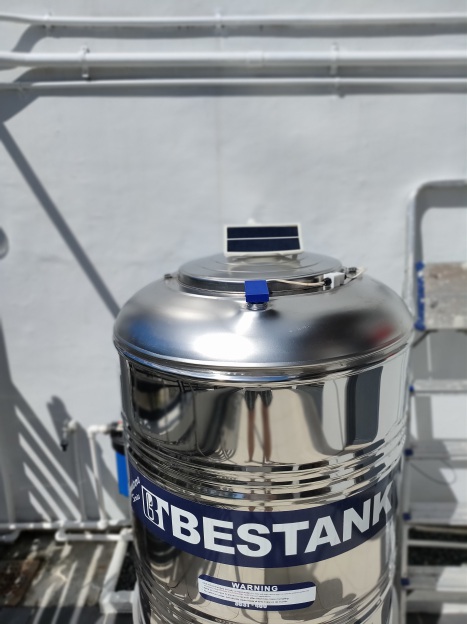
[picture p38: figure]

To protect the inside of the enclosure from condensing water from the tank the opening at the IR ToF sensor is sealed with a peace of plastic glued to the enclosure:

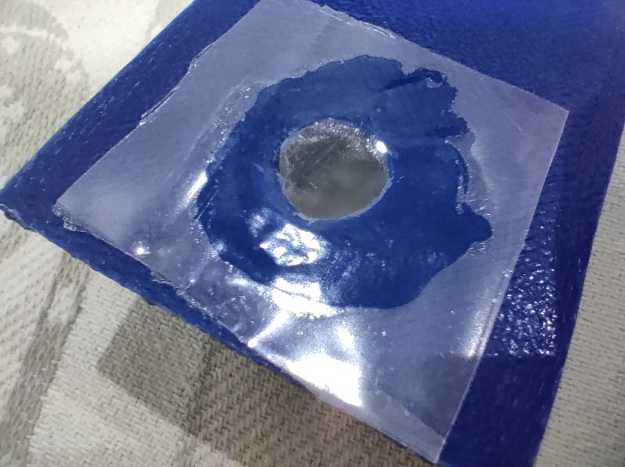
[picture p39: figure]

# Hardware used

RAK4631 (https://docs.rakwireless.com/Product-Categories/WisBlock/RAK4631/Overview/) WisBlock Core module

RAK5005-O (https://docs.rakwireless.com/Product-Categories/WisBlock/RAK5005-O/Overview/) WisBlock Base board

RAK12017 (https://docs.rakwireless.com/Product-Categories/WisBlock/RAK12017/Overview/) WisBlock IR sensor

RAK1904 (https://docs.rakwireless.com/Product-Categories/WisBlock/RAK1904/Overview) WisBlock Acceleration sensor

## Power consumption

The application does switch off the IR ToF module and the MCU and LoRa transceiver go into sleep mode between measurement cycles to save power. I could measure a sleep current of 20-40uA of the whole system.

# Software used

PlatformIO (https://platformio.org/install)

Adafruit nRF52 BSP (https://docs.platformio.org/en/latest/boards/nordicnrf52/adafruit_feather_nrf52832.html)

Patch to use RAK4631 with PlatformIO (https://github.com/RAKWireless/WisBlock/blob/master/PlatformIO/RAK4630/README.md)

SX126x-Arduino LoRaWAN library (https://github.com/beegee-tokyo/SX126x-Arduino)

WisBlock-API (https://platformio.org/lib/show/12807/WisBlock-API)

SparkFun LIS3DH Arduino Library (https://platformio.org/lib/show/1401/SparkFun%20LIS3DH%20Arduino%20Library)

## REMARK

The libraries are all listed in the platformio.ini and are automatically installed when the project is compiled.

# Setting up LoRaWAN credentials

The LoRaWAN settings can be defined in three different ways.

Over BLE with WisBlock Toolbox (https://play.google.com/store/apps/details?id=tk.giesecke.wisblock_toolbox)

Over USB with AT Commands

Hardcoded in the sources (ABSOLUTELY NOT RECOMMENDED)

## 1) Setup over BLE

Using the WisBlock Toolbox (https://play.google.com/store/apps/details?id=tk.giesecke.wisblock_toolbox) you can connect to the WisBlock over BLE and setup all LoRaWAN parameters like

Region

OTAA/ABP

Confirmed/Unconfirmed message

More details can be found in the WisBlock Toolbox (https://github.com/beegee-tokyo/WisBlock-Toolbox#readme)

The device is advertising over BLE only the first 30 seconds after power up and then again for 15 seconds after wakeup for measurements. The device is advertising as RAK-GNSS-xx where xx is the BLE MAC address of the device.

## 2) Setup over USB port

Using the AT command interface the WisBlock can be setup over the USB port.

A detailed manual for the AT commands are in AT-Commands.md

Here is an example for the typical AT commands required to get the device ready (EUI's and Keys are examples):

// Setup AppEUI
AT+APPEUI=70b3d57ed00201e1 // Setup DevEUI
AT+DEVEUI=ac1f09fffe03efdc
// Setup AppKey
AT+APPKEY=2b84e0b09b68e5cb42176fe753dcee79 // Set automatic send frequency in seconds AT+SENDFREQ=60
// Set data rate
AT+DR=3
// Set LoRaWAN region (here US915) AT+BAND=8
// Reset node to save the new parameters ATZ
// After reboot, start join request AT+JOIN=1,0,8,10

## REMARK

The AT command format used here is NOT compatible with the RAK5205/RAK7205 AT commands.

## 3) Hardcoded LoRaWAN settings

void api_set_credentials(void); This informs the API that hard coded LoRaWAN credentials will be used. If credentials are sent over USB or from My nRF Toolbox, the received credentials will be ignored. It is strongly suggest NOT TO USE hard coded credentials to avoid duplicate node definitions
If hard coded LoRaWAN credentials are used, they must be set before this function is called. Example:

g_lorawan_settings.auto_join = false; | // Flag if node joins automatically after
reboot
g_lorawan_settings.otaa_enabled = true; | // Flag for OTAA or ABP
memcpy(g_lorawan_settings.node_device_eui, node_device_eui, 8); // OTAA Device EUI MSB memcpy(g_lorawan_settings.node_app_eui, node_app_eui, 8); // OTAA Application EUI MSB memcpy(g_lorawan_settings.node_app_key, node_app_key, 16); // OTAA Application Key MSB memcpy(g_lorawan_settings.node_nws_key, node_nws_key, 16); // ABP Network Session Key MSB
memcpy(g_lorawan_settings.node_apps_key, node_apps_key, 16); // ABP Application Session key MSB
g_lorawan_settings.node_dev_addr = 0x26021FB4; | // ABP Device Address MSB
g_lorawan_settings.send_repeat_time = 120000; | // Send repeat time in milliseconds: 2
* 60 * 1000 => 2 minutes
g_lorawan_settings.adr_enabled = false; | // Flag for ADR on or off
g_lorawan_settings.public_network = true; | // Flag for public or private network
g_lorawan_settings.duty_cycle_enabled = false; | // Flag to enable duty cycle
(validity depends on Region)
g_lorawan_settings.join_trials = 5; | // Number of join retries
g_lorawan_settings.tx_power = 0; | // TX power 0 .. 15 (validity depends on Region)
g_lorawan_settings.data_rate = 3; | // Data rate 0 .. 15 (validity depends on
Region)
g_lorawan_settings.lora_class = 0; | // LoRaWAN class 0: A, 2: C, 1: B is not
supported
g_lorawan_settings.subband_channels = 1; | // Subband channel selection 1 .. 9
g_lorawan_settings.app_port = 2; | // Data port to send data
g_lorawan_settings.confirmed_msg_enabled = LMH_UNCONFIRMED_MSG; // Flag to enable confirmed messages
g_lorawan_settings.resetRequest = true; | // Command from BLE to reset device
g_lorawan_settings.lora_region = LORAMAC_REGION_AS923_3; // LoRa region
// Inform API about hard coded LoRaWAN settings
api_set_credentials();

REMARK!
Hard coded credentials must be set in void setup_app(void) !

# Packet data format

The packet data is in Cayenne LPP format. Every time the

# Compiled output

The compiled files are located in the ./Generated folder. Each successful compiled version is named as WisBlock_WL_Vx.y.z_YYYYMMddhhmmss
x.y.z is the version number. The version number is setup in the ./platformio.ini file.
YYYYMMddhhmmss is the timestamp of the compilation.

The generated .zip file can be used as well to update the device over BLE using either My nRF52 Toolbox repo or Nordic nRF Toolbox or nRF Connect (https://github.com/beegee-tokyo/My-nRF52-Toolbox/blob/master/README.md)

# Debug options

Debug output can be controlled by defines in the platformio.ini LIB_DEBUG controls debug output of the SX126x-Arduino LoRaWAN library

0 → No debug outpuy

1 → Library debug output (not recommended, can have influence on timing)

MY_DEBUG controls debug output of the application itself

0 → No debug outpuy

1 → Application debug output

CFG_DEBUG controls the debug output of the nRF52 BSP. It is recommended to keep it off

## Example for no debug output and maximum power savings:

[env:wiscore_rak4631]
platform = nordicnrf52
board = wiscore_rak4631
framework = arduino
build_flags =
; -DCFG_DEBUG=2
-DSW_VERSION_1=1 ; major version increase on API change / not backwards compatible -DSW_VERSION_2=0 ; minor version increase on API change / backward compatible -DSW_VERSION_3=0 ; patch version increase on bugfix, no affect on API
-DLIB_DEBUG=0 | ; 0 Disable LoRaWAN debug output
-DMY_DEBUG=0 | ; 0 Disable application debug output
-DNO_BLE_LED=1 | ; 1 Disable blue LED as BLE notificator
lib_deps =
beegee-tokyo/SX126x-Arduino
sparkfun/SparkFun LIS3DH Arduino Library https://github.com/beegee-tokyo/WisBlock-APIextra_scripts = pre:rename.py

created with thefreeversion of Markdown Monster (https://markdownmonster.west-wind.com)

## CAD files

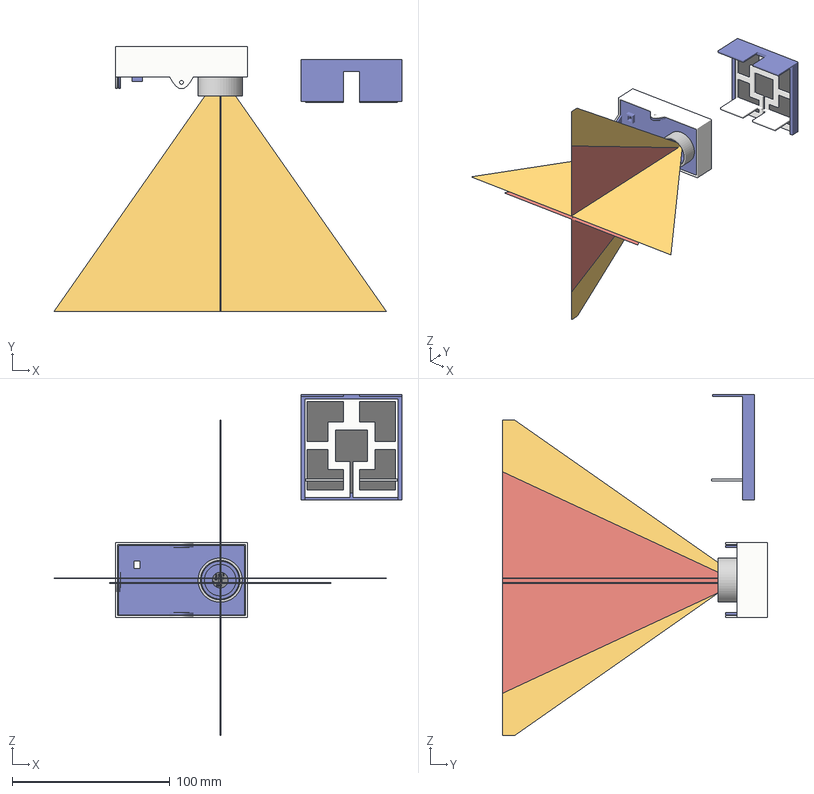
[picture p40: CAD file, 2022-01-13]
assets/3D/Watertank-Sensor RAK12014.3mf
220.3 x 167.7 x 216.2 mm
Bottom-RAK12014 (1)
Lid-RAK12014
RX Beam
Solar-3
Solar-4
TX Beam
Tank-Opening

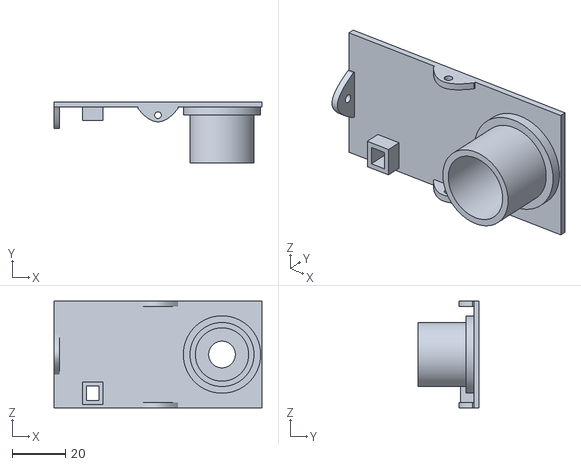
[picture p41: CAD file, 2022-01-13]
assets/Bottom.stl
78.0 x 23.0 x 40.0

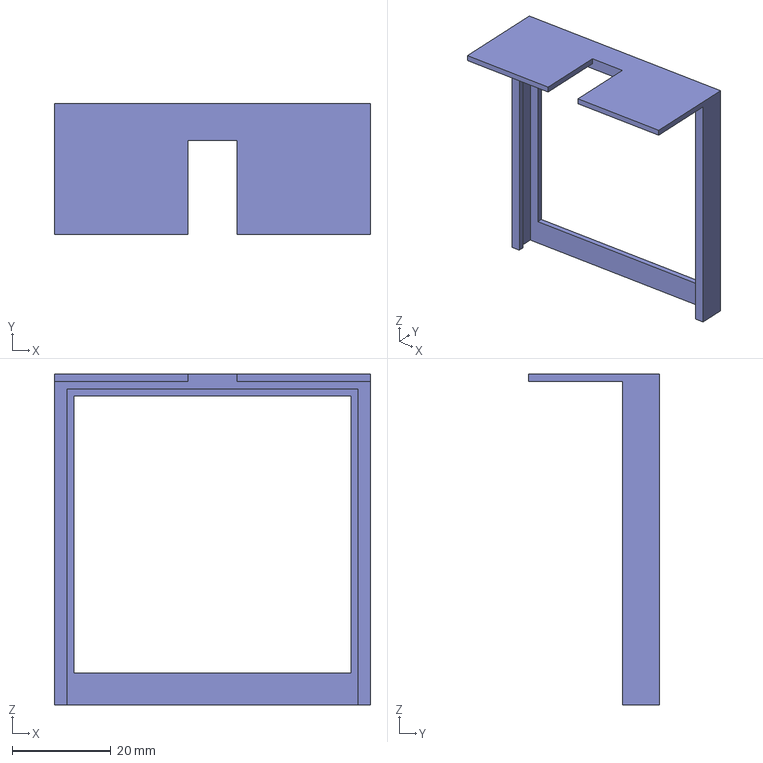
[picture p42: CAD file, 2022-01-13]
assets/3D/Solar-3.step
64.0 x 26.5 x 67.0 mm

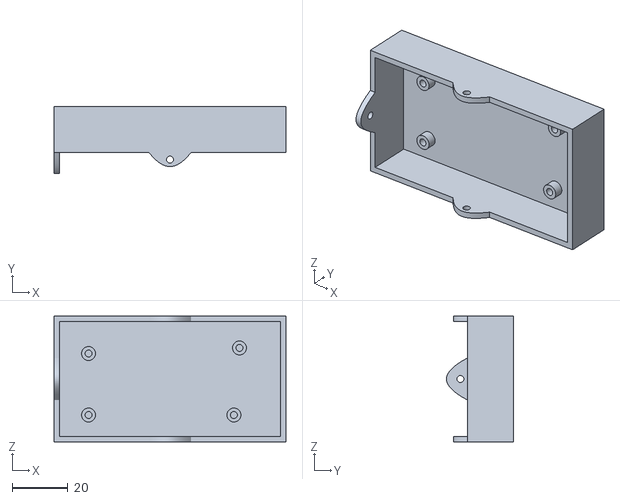
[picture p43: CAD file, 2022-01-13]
assets/Lid.stl
83.0 x 24.0 x 45.0

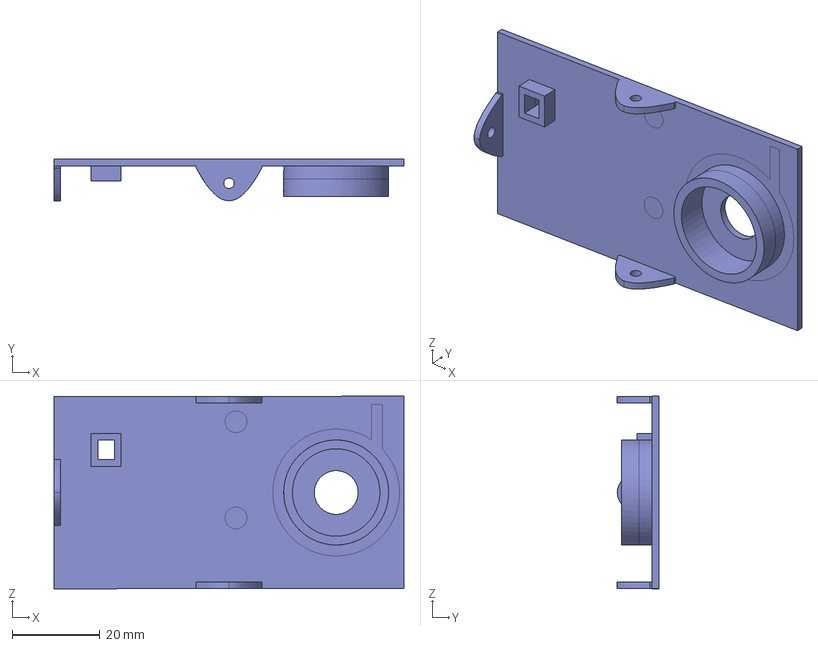
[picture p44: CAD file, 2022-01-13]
assets/3D/Bottom-RAK12014.step
80.0 x 9.50 x 44.0 mm

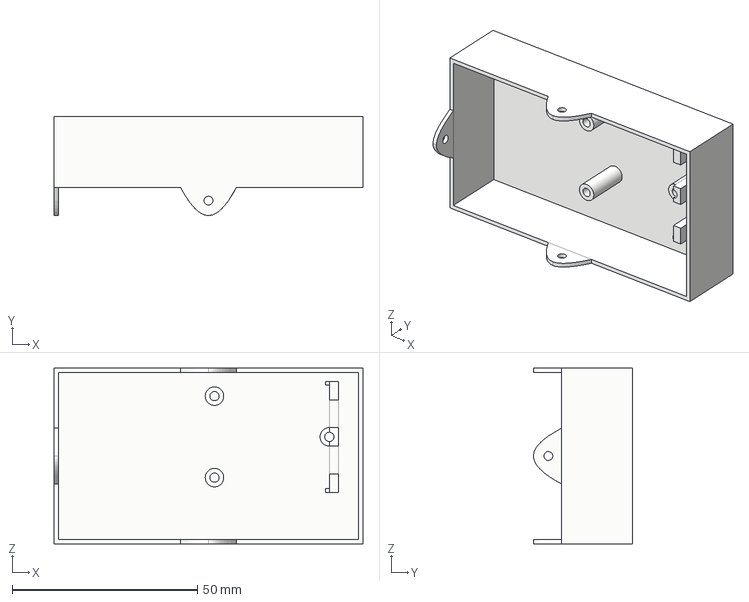
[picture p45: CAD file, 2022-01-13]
assets/3D/Lid-RAK12014.step
83.4 x 26.7 x 47.4 mm

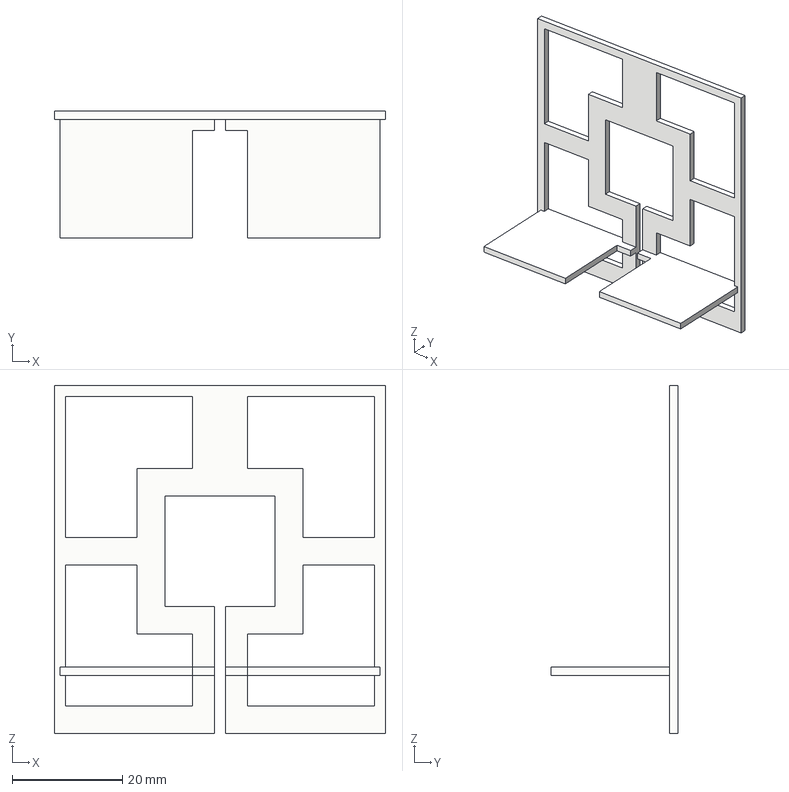
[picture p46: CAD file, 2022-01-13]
assets/3D/Solar-4.step
60.0 x 23.0 x 63.0 mm

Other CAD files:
assets/3D/Bottom-RAK12014.stl
assets/3D/Lid-RAK12014.stl

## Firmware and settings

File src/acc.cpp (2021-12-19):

/**
 * @file acc.cpp
 * @author Bernd Giesecke (bernd.giesecke@rakwireless.com)
 * @brief 3-axis accelerometer functions
 * @version 0.1
 * @date 2020-07-24
 * 
 * @copyright Copyright (c) 2020
 * 
 */
#include "app.h"

void acc_int_callback(void);

/** The LIS3DH sensor */
LIS3DH acc_sensor(I2C_MODE, 0x18);

/**
 * @brief Initialize LIS3DH 3-axis 
 * acceleration sensor
 * 
 * @return true If sensor was found and is initialized
 * @return false If sensor initialization failed
 */
bool init_acc(void)
{
	// Setup interrupt pin
	pinMode(INT1_PIN, INPUT);

	Wire.begin();

	acc_sensor.settings.accelSampleRate = 10; //Hz.  Can be: 0,1,10,25,50,100,200,400,1600,5000 Hz
	acc_sensor.settings.accelRange = 2;		  //Max G force readable.  Can be: 2, 4, 8, 16

	acc_sensor.settings.adcEnabled = 0;
	acc_sensor.settings.tempEnabled = 0;
	acc_sensor.settings.xAccelEnabled = 1;
	acc_sensor.settings.yAccelEnabled = 1;
	acc_sensor.settings.zAccelEnabled = 1;

	if (acc_sensor.begin() != 0)
	{
		MYLOG("ACC", "ACC sensor initialization failed");
		return false;
	}

	uint8_t data_to_write = 0;
	// Enable interrupts
	data_to_write |= 0x20;									  //Z high
	data_to_write |= 0x08;									  //Y high
	data_to_write |= 0x02;									  //X high
	acc_sensor.writeRegister(LIS3DH_INT1_CFG, data_to_write); // Enable interrupts on high tresholds for x, y and z

	// Set interrupt trigger range
	data_to_write = 0;
	// data_to_write |= 0x10;									  // 1/8 range
	// acc_sensor.writeRegister(LIS3DH_INT1_THS, data_to_write); // 1/8th range
	data_to_write |= 0x08;									  // 1/16 range
	acc_sensor.writeRegister(LIS3DH_INT1_THS, data_to_write); // 1/16th range

	// Set interrupt signal length
	data_to_write = 0;
	data_to_write |= 0x01; // 1 * 1/50 s = 20ms
	acc_sensor.writeRegister(LIS3DH_INT1_DURATION, data_to_write);

	acc_sensor.readRegister(&data_to_write, LIS3DH_CTRL_REG5);
	data_to_write &= 0xF3;									   //Clear bits of interest
	data_to_write |= 0x08;									   //Latch interrupt (Cleared by reading int1_src)
	acc_sensor.writeRegister(LIS3DH_CTRL_REG5, data_to_write); // Set interrupt to latching

	// Select interrupt pin 1
	data_to_write = 0;
	data_to_write |= 0x40; //AOI1 event (Generator 1 interrupt on pin 1)
	data_to_write |= 0x20; //AOI2 event ()
	acc_sensor.writeRegister(LIS3DH_CTRL_REG3, data_to_write);

	// No interrupt on pin 2
	acc_sensor.writeRegister(LIS3DH_CTRL_REG6, 0x00); 

	// Enable high pass filter
	acc_sensor.writeRegister(LIS3DH_CTRL_REG2, 0x01); 

	// Set low power mode
	data_to_write = 0;
	acc_sensor.readRegister(&data_to_write, LIS3DH_CTRL_REG1);
	data_to_write |= 0x08;
	acc_sensor.writeRegister(LIS3DH_CTRL_REG1, data_to_write);
	delay(100);

	data_to_write = 0;
	acc_sensor.readRegister(&data_to_write, 0x1E);
	data_to_write |= 0x90;
	acc_sensor.writeRegister(0x1E, data_to_write);
	delay(100);

	clear_acc_int();

	// Set the interrupt callback function
	attachInterrupt(INT1_PIN, acc_int_callback, RISING);

	read_acc();
	
	return true;
}

/**
 * @brief Read values from ACC sensor
 * 		Used only for debugging to print the values
 * 
 */
void read_acc(void)
{
	int16_t acc_x = (int16_t)(acc_sensor.readFloatAccelX() * 1000.0);
	int16_t acc_y = (int16_t)(acc_sensor.readFloatAccelY() * 1000.0);
	int16_t acc_z = (int16_t)(acc_sensor.readFloatAccelZ() * 1000.0);

	MYLOG("ACC", "X %.3f %.3f %d", acc_sensor.readFloatAccelX(), acc_sensor.readFloatAccelX() * 1000.0, acc_x);
	MYLOG("ACC", "Y %.3f %.3f %d", acc_sensor.readFloatAccelY(), acc_sensor.readFloatAccelY() * 1000.0, acc_y);
	MYLOG("ACC", "Z %.3f %.3f %d", acc_sensor.readFloatAccelZ(), acc_sensor.readFloatAccelZ() * 1000.0, acc_z);
}

/**
 * @brief ACC interrupt handler
 * @note gives semaphore to wake up main loop
 * 
 */
void acc_int_callback(void)
{
	g_task_event_type |= ACC_TRIGGER;
	xSemaphoreGiveFromISR(g_task_sem, pdFALSE);
}

/**
 * @brief Clear ACC interrupt register to enable next wakeup
 * 
 */
void clear_acc_int(void)
{
	uint8_t data_read;
	acc_sensor.readRegister(&data_read, LIS3DH_INT1_SRC);
	if (data_read & 0x40)
		MYLOG("ACC", "Interrupt Active 0x%X", data_read);
	if (data_read & 0x20)
		MYLOG("ACC", "Z high");
	if (data_read & 0x10)
		MYLOG("ACC", "Z low");
	if (data_read & 0x08)
		MYLOG("ACC", "Y high");
	if (data_read & 0x04)
		MYLOG("ACC", "Y low");
	if (data_read & 0x02)
		MYLOG("ACC", "X high");
	if (data_read & 0x01)
		MYLOG("ACC", "X low");
}

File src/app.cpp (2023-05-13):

/**
 * @file app.cpp
 * @author Bernd Giesecke (bernd.giesecke@rakwireless.com)
 * @brief Application specific functions. Mandatory to have init_app(),
 *        app_event_handler(), ble_data_handler(), lora_data_handler()
 *        and lora_tx_finished()
 * @version 0.1
 * @date 2021-04-23
 *
 * @copyright Copyright (c) 2021
 *
 */

#include "app.h"

/** Set the device name, max length is 10 characters */
char g_ble_dev_name[10] = "MHC-WL";

/** Required for give semaphore from ISR */
BaseType_t g_higher_priority_task_woken = pdTRUE;

/** Send Fail counter **/
uint8_t send_fail = 0;

/** LoRaWAN packet */
WisCayenne g_solution_data(255);

/** Battery level uinion */
analog_s batt_level;

/**
 * @brief Application specific setup functions
 *
 */
void setup_app(void)
{
	// Enable BLE
	g_enable_ble = true;
#if API_DEBUG == 0
#if MY_DEBUG > 0
	// Initialize Serial for debug output
	Serial.begin(115200);

	time_t serial_timeout = millis();
	// On nRF52840 the USB serial is not available immediately
	while (!Serial)
	{
		if ((millis() - serial_timeout) < 5000)
		{
			delay(100);
			digitalWrite(LED_BUILTIN, !digitalRead(LED_BUILTIN));
		}
		else
		{
			break;
		}
	}
#endif
#endif
}

/**
 * @brief Application specific initializations
 *
 * @return true Initialization success
 * @return false Initialization failure
 */
bool init_app(void)
{
	bool result = true;
	MYLOG("APP", "init_app");

	// COnfigure supply control IO
	pinMode(WB_IO2, OUTPUT);

	// Start I2C
	Wire.begin();

	result = init_tof();

	// Initialize ACC sensor
	result |= init_acc();

	// Reset the packet
	g_solution_data.reset();

	return result;
}

/**
 * @brief Application specific event handler
 *        Requires as minimum the handling of STATUS event
 *        Here you handle as well your application specific events
 */
void app_event_handler(void)
{
	// Timer triggered event
	if ((g_task_event_type & STATUS) == STATUS)
	{
		g_task_event_type &= N_STATUS;
		MYLOG("APP", "Timer wakeup");

		// Reset the packet
		g_solution_data.reset();

		// Get water level
		get_water_level();

		// Get Battery status
		float batt_level_f = read_batt();
		g_solution_data.addVoltage(LPP_CHANNEL_BATT, batt_level_f / 1000.0);

		if (g_lorawan_settings.lorawan_enable)
		{
			// Send water level status
			lmh_error_status result = send_lora_packet(g_solution_data.getBuffer(), g_solution_data.getSize());
			switch (result)
			{
			case LMH_SUCCESS:
				MYLOG("APP", "Packet enqueued");
				break;
			case LMH_BUSY:
				MYLOG("APP", "LoRa transceiver is busy");
				AT_PRINTF("+EVT:BUSY_ERROR\n");
				break;
			case LMH_ERROR:
				MYLOG("APP", "Packet error, too big to send with current DR");
				AT_PRINTF("+EVT:DR_ERROR\n");
				break;
			}
		}
		else
		{
			// Add the device DevEUI as a device ID to the packet
			uint8_t packet_buffer[g_solution_data.getSize() + 8];
			memcpy(packet_buffer, g_lorawan_settings.node_device_eui, 8);
			memcpy(&packet_buffer[8], g_solution_data.getBuffer(), g_solution_data.getSize());

			// Send packet over LoRa
			if (send_p2p_packet(packet_buffer, g_solution_data.getSize() + 8))
			{
				MYLOG("APP", "Packet enqueued");
			}
			else
			{
				AT_PRINTF("+EVT:SIZE_ERROR\n");
				MYLOG("APP", "Packet too big");
			}
		}
	}

	// ACC trigger event
	if ((g_task_event_type & ACC_TRIGGER) == ACC_TRIGGER)
	{
		g_task_event_type &= N_ACC_TRIGGER;
		MYLOG("APP", "ACC triggered");

		read_acc();
		clear_acc_int();
		restart_advertising(15);
	}
}

/**
 * @brief Handle BLE UART data
 *
 */
void ble_data_handler(void)
{
	if (g_enable_ble)
	{
		// BLE UART data handling
		if ((g_task_event_type & BLE_DATA) == BLE_DATA)
		{
			MYLOG("AT", "RECEIVED BLE");
			/** BLE UART data arrived */
			g_task_event_type &= N_BLE_DATA;

			while (g_ble_uart.available() > 0)
			{
				at_serial_input(uint8_t(g_ble_uart.read()));
				delay(5);
			}
			at_serial_input(uint8_t('\n'));
		}
	}
}

/**
 * @brief Handle received LoRa Data
 *
 */
void lora_data_handler(void)
{

	// LoRa Join finished handling
	if ((g_task_event_type & LORA_JOIN_FIN) == LORA_JOIN_FIN)
	{
		g_task_event_type &= N_LORA_JOIN_FIN;
		if (g_join_result)
		{
			MYLOG("APP", "Successfully joined network");
		}
		else
		{
			MYLOG("APP", "Join network failed");
			/// \todo here join could be restarted.
			lmh_join();

			// If BLE is enabled, restart Advertising
			if (g_enable_ble)
			{
				restart_advertising(15);
			}
		}
	}

	// LoRa TX finished handling
	if ((g_task_event_type & LORA_TX_FIN) == LORA_TX_FIN)
	{
		g_task_event_type &= N_LORA_TX_FIN;

		MYLOG("APP", "LPWAN TX cycle %s", g_rx_fin_result ? "finished ACK" : "failed NAK");

		if (!g_rx_fin_result)
		{
			// Increase fail send counter
			send_fail++;

			if (send_fail == 10)
			{
				// Too many failed sendings, reset node and try to rejoin
				delay(100);
				sd_nvic_SystemReset();
			}
		}
	}

	// LoRa data handling
	if ((g_task_event_type & LORA_DATA) == LORA_DATA)
	{
		/**************************************************************/
		/**************************************************************/
		/// \todo LoRa data arrived
		/// \todo parse them here
		/**************************************************************/
		/**************************************************************/
		g_task_event_type &= N_LORA_DATA;
		MYLOG("APP", "Received package over LoRa");
		char log_buff[g_rx_data_len * 3] = {0};
		uint8_t log_idx = 0;
		for (int idx = 0; idx < g_rx_data_len; idx++)
		{
			sprintf(&log_buff[log_idx], "%02X ", g_rx_lora_data[idx]);
			log_idx += 3;
		}
		MYLOG("APP", "%s", log_buff);
	}
}

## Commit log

2021-12-19 Add the sources
    [Bottom-RAK12014.stl, Lid-RAK12014.stl, Solar-1.stl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]
2022-01-13 Fix Repo Mixup
    [Bottom-RAK12014.step, Bottom-RAK12014.stl, Bottom.stl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]
2023-05-13 Switch to WisBlock-API-V2, add create UF2
